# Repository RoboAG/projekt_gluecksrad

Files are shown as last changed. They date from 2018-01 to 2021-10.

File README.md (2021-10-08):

# projekt_gluecksrad
Bau eines elektrischen Glücksrades für schulische Veranstaltungen



Hier gibt es eine kleines [Demo-Video](https://www.youtube.com/watch?v=hORIZUaodIo&list=PL4P27g8g4QtTZY6d-4PRqTHP1PGKIp_SS) und eine [Bedienungsanleitung](Software/Keplertag_2021/README.md)([pdf](Anleitung/Anleitung_Bedienung.pdf)).

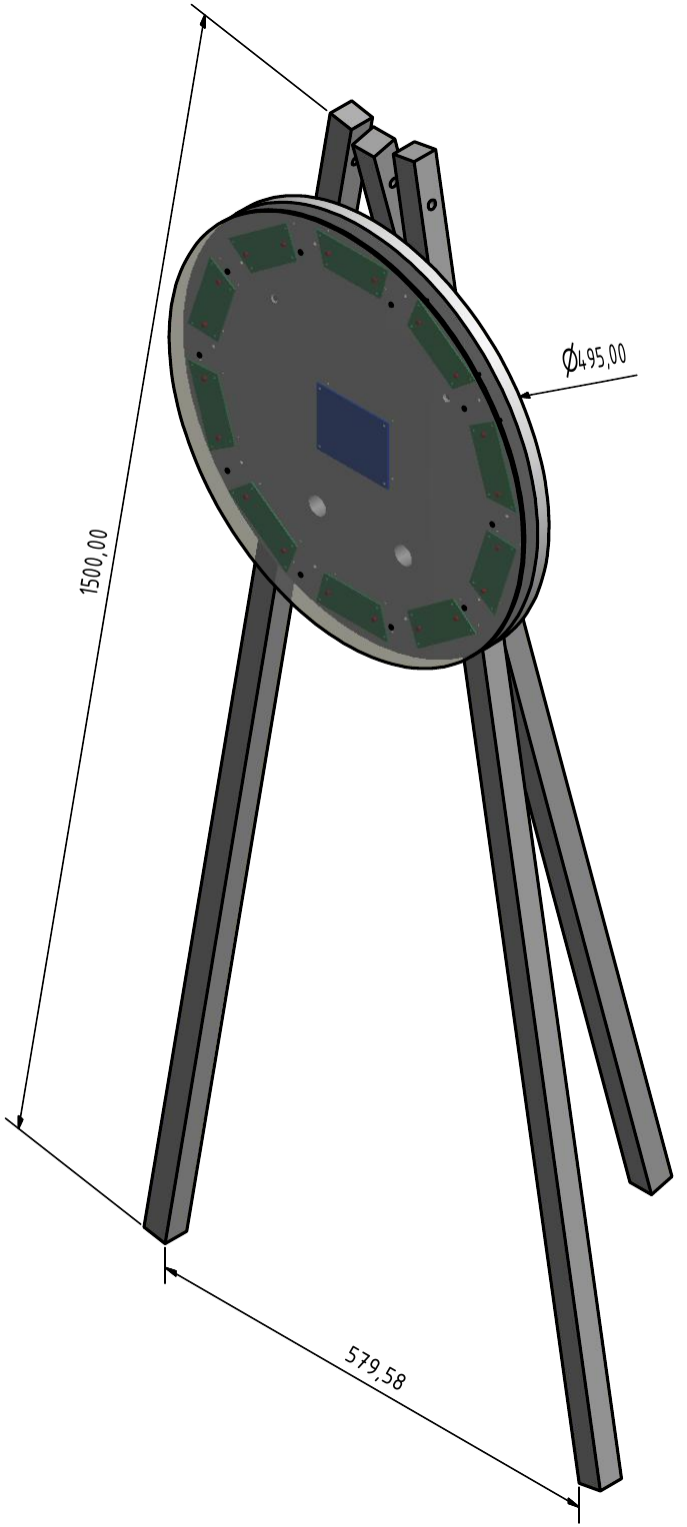
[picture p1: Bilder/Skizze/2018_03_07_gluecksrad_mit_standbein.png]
Skizze des geplanten Aufbaus


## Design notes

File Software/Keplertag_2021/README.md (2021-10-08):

# Glücksrad

## Hardware
Die gesamte Steuerung des Glücksrades erfolgt über zwei Knöpfe:

- Bumper     : extern am Glücksrad anzuschließender goldener Riesenknopf
- Mode-Button: kleiner, roter Knopf auf der Rückseite des Glücksrades

## Start
Beim Einschalten des Glücksrades wird automatisch der letzte Modus und die gespeicherte (Rest-)Preisliste geladen.
Anschließend wird der geladene Modus durch 1-sekündiges Aufleuchten aller LEDs dargestellt.

| Farbe | Modus | Folgestatus |
| ----- | --- | --- |
| grün  | Standard | Demo-Animation |
| gelb  | Countdown  | Demo- oder Preise-Leer-Animation |
| rot | Ladefehler | Demo-Animation (wechsel zu Standard) |

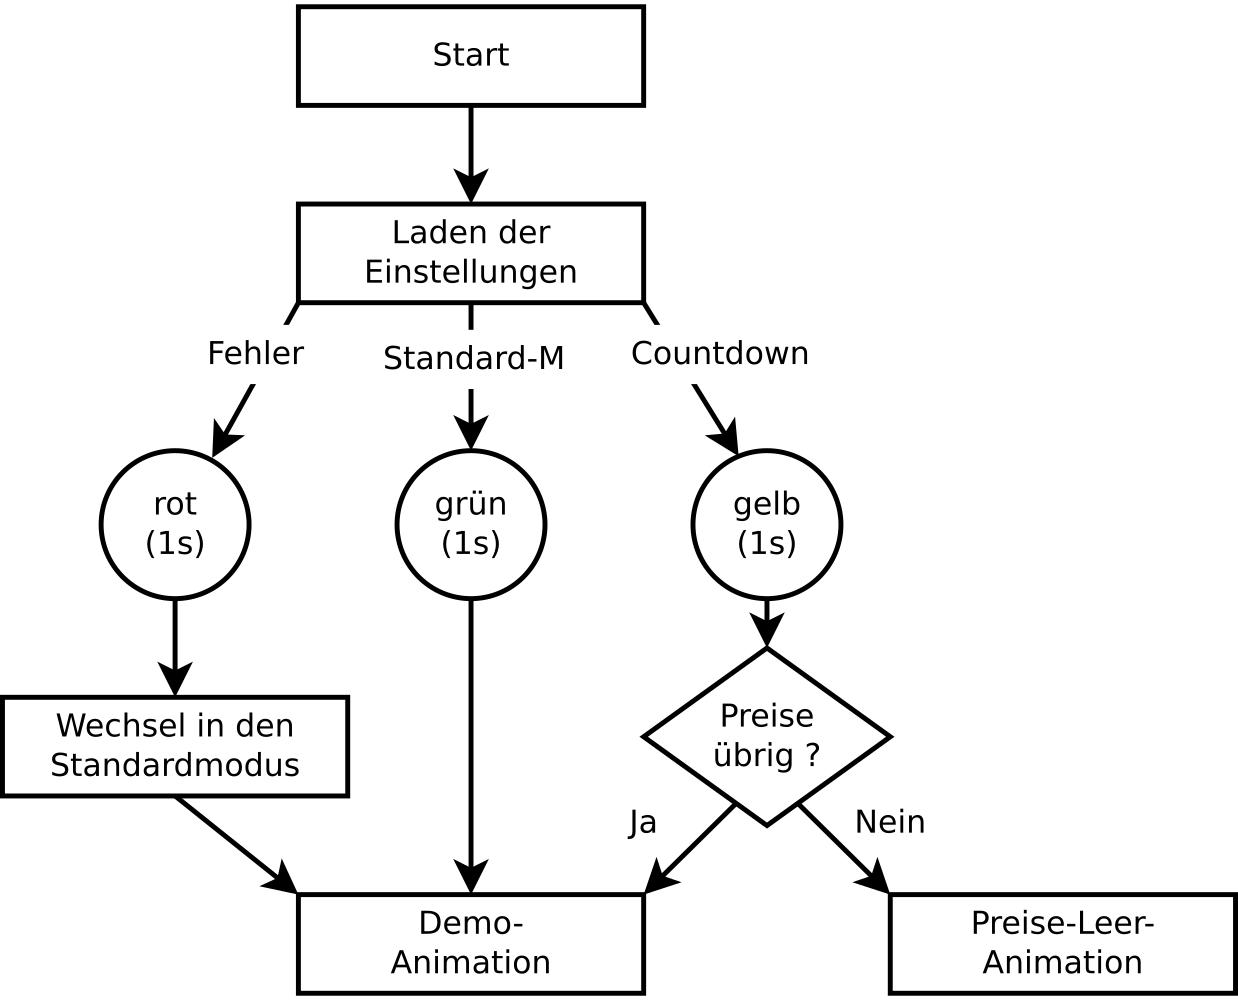
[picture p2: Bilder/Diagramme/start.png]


## Drehen & Modi
Befindet sich das Glücksrad in der Demo-Animation kann durch Drücken auf den Bumper die Drehanimation ausgelöst werden.
Sobald das Glücksrad auf einem zufälligen Feld zur Ruhe gekommen ist, startet die Preis-Animationen für die entsprechende Farbe.
Nur durch Betätigen des Mode-Button kann das Glücksrad zurück in die Demo-Animation wechseln.

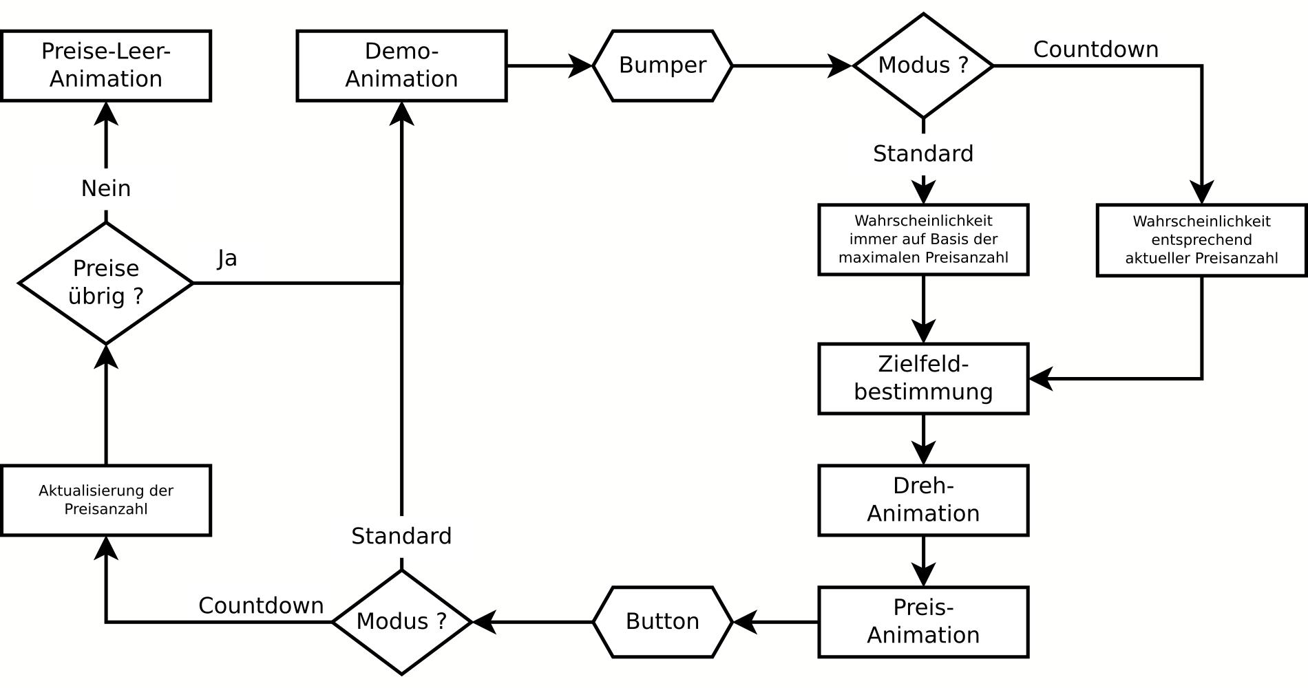
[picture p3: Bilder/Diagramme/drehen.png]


## Preise
Es gibt insgesamt fünf verschiedene Preiskategorien mit unterschiedlicher Wertigkeit.
Die Wahrscheinlichkeiten einen Preis zu erhalten ist nur abhängig von der Anzahl der hinterlegten bzw. verbleibenden Preise.

### Keplertag 2021
Beim Keplertag sind nur vier der fünf möglichen Preiskategorien belegt.

| Preis | Anzahl der LEDs | Keplertag 2021 |
| --- | --- | --- |
| rubin (rot)  |  2 von 20 (10%) | 36 |
| saphir  (blau) |  4 von 20 (20%) | 75 |
| silber  (weiß) |  7 von 20 (35%) | 750 |
| gold (gelb) |  7 von 20 (35%) | 750 |

### Frühlingsfest 2018 & 2019

| Preis | Anzahl der LEDs | Frühlingsfest 2019 | Frühlingsfest 2018 |
| --- | --- | --- | --- |
| gold (gelb) |  1 von 20 (5%)  | 9 | 5 |
| silber  (weiß) |  1 von 20 (5%)  | 11 | 15 |
| rubin (rot)  |  4 von 20 (20%) | 38 | 150 |
| smaragd (grün) |  4 von 20 (20%) | 70 | 150 |
| saphir  (blau) | 10 von 20 (50%) | 170 | 300 |

Beispielsweise war die initiale Wahrscheinlichkeit beim Frühlingsfest 2018 einen goldenen Preis zu gewinnen ca. 0.8%.

    5 / (5 + 15 + 150 + 150 + 300) ~ 0.0080645 ~ 0.8%

## Einstellungsmenü

Das Glücksrad hat ein (verstecktes) Einstellungsmenü.
Es kann nur durch 3-sekündiges Drücken des Mode-Button in der Demo- oder der Preise-Leer-Animation erreicht werden.

Der ausgewählte Menüpunkt kann durch eine kurze Betätigung des Mode-Buttons gewechselt werden:

| Menü | Bedeutung |
| ---- | --- |
| blau | Einstellungsmenü abbrechen |
| grün | Wechsel in den Standardmodus |
| gelb | Wechsel in den Countdown-Modus |
| rot  | Reset der internen Preisliste & Wechsel in den Countdown-Modus |

Durch ein 3-sekündiges Drücken des Mode-Button wird der aktuelle Menüpunkt ausgelöst.
Danach verlässt das Glücksrad das Einstellungsmenü automatisch.

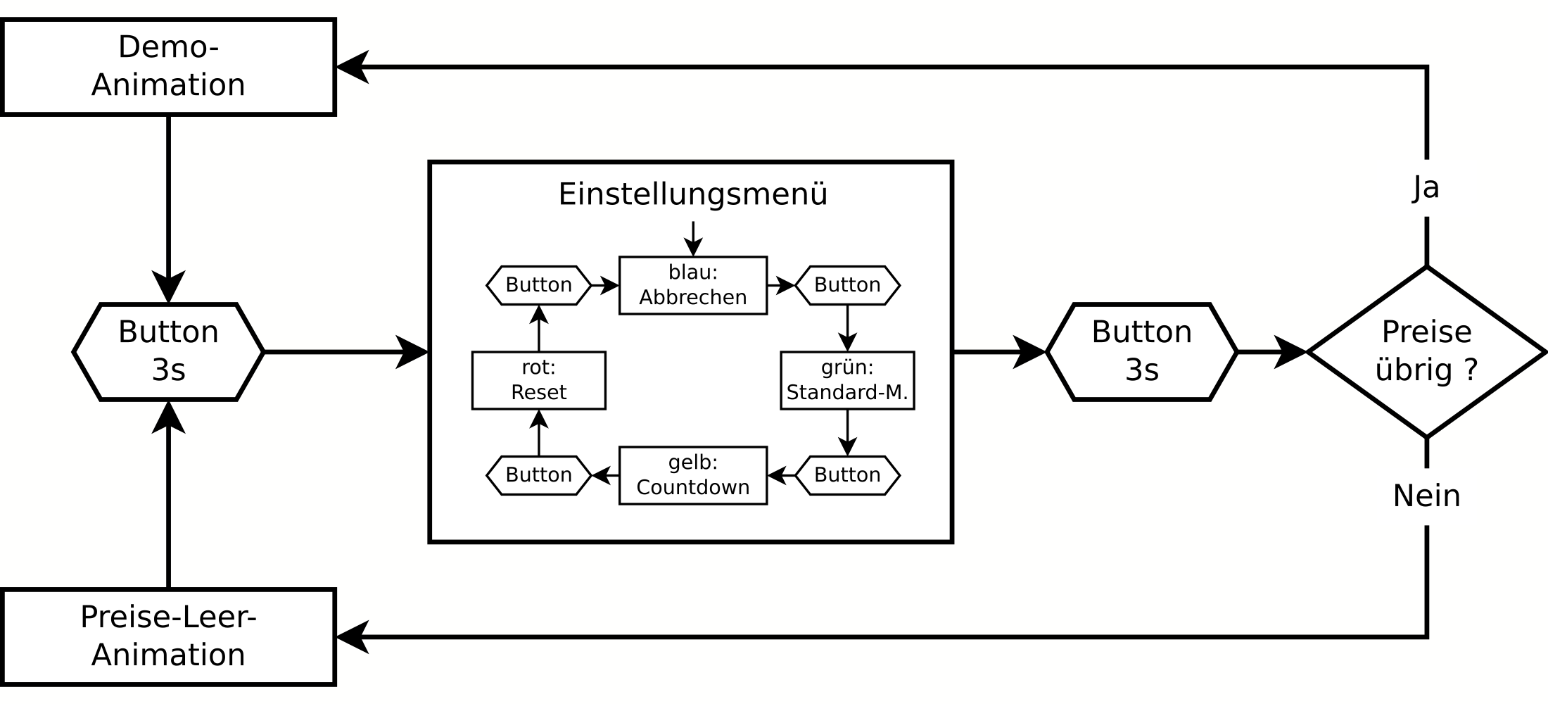
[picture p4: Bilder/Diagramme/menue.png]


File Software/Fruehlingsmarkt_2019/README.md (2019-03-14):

# Glücksrad

## Preise

- Preise
    - es gibt insgesamt 5 verschiedene Preiskategorien mit absteigender Preiswertigkeit:
        - 1: gold (gelb)
        - 2: silber (weiß)
        - 3: rubin (rot)
        - 4: smaragd (grün)
        - 5: saphir (blau)
    - die Wahrscheinlichkeiten sind im Verhältnis von verbleibender Anzahl zur übrigen Gesamtpreiszahl verteilt

## Start:

- es wird der letzte Glücksrad-Modus geladen, ggf. die gespeicherte Preisliste
- der geladene Modus wird durch 1-sekündiges Leuchten aller LEDs angezeigt:
    - grün: Standard
    - gelb: Lenz
- es startet die Demo-Animation

## Drehen:

- durch Drücken auf den Bumper im Demo-Modus wird die Dreh-Animation zu einem zufälligen Feld ausgelöst
- danach leuchten die LEDs in 3 verschiedenen Animationen (je nach Preisklasse) in der erdrehten Farbe auf
- während beider Vorgänge ist der Bumper blockiert
- durch drücken des Mode-Buttons wird die Animation beendet und der Bumper freigegeben

## Bedienung
- Buttons:
    - es gibt insgesamt zwei Buttons:
        - Bumper: extern am Glücksrad anzuschließender Riesenknopf
        - Mode:   kleiner, roter, an der Rückseite des Glücksrades befestigter Knopf

## Menü:

- durch 3-sekündiges Drücken des Mode-Buttons im Demo-Modus oder während der 'Preise-Leer' Animation wird das Menü angezeigt
- Navigiert wird mithilfe des Mode-Buttons
- Ausgewählt wird durch 3-sekündiges Drücken auf den Bumper
- zurzeit gibt es 4 Menüpunkte:
    - Blau: beendet das Menü ohne eine Aktion
    - Grün: wechselt in den Standard-Modus
    - Gelb: wechselt in den Lenz-Modus
    - Rot : resettet die Preisliste

## Modi:

- Standard
    - die Preisverteilung entspricht den Standard-Lenz-Werten und bleibt konstant
- Lenz
    - die Wahrscheinlichkeiten werden nach jedem Dreh entsprechend der Anzahl verbleibenden Preise verteilt
    - wenn alle Preise verteilt wurden (Summe der verbleibenden Preise = 0) wird dies durch eine Blink-Animation in den normalen Preisfarben kundgetan

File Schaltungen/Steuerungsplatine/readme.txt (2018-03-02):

Die Steuerungsplatine entspricht der THT-Version der Licht-Platine des RoboSAX:
    https://github.com/RoboSAX/eagle_licht

Es wird nur auf einige Bauteile bei der Bestückung verzichtet. Diese reduzierte Variante ist hier gespeichert.

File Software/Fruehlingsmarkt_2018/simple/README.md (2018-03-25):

# Glücksrad

**Allgemeines**
-------------
Allgemeine Beschreibung siehe [hier](../README.md).

**Start:**
----------
- durch gedrückt-halten des Mode-Buttons wird der Lenz-Modus geladen. Andernfalls der Standard-Modus
- der geladene Modus wird durch 1-sekündiges Leuchten aller LEDs angezeigt:
    - grün: Standard
    - gelb: Lenz
- es startet die Demo-Animation

**Resetten:**
-------------
- durch 5-sekündiges Drücken des Mode-Buttons im Demo-Modus oder bei leerer Preisliste wird diese zurückgesetzt

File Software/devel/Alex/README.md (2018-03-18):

# Glücksrad-Logik

Preisverteilung
---------------
- Kategorie 1: 300
- Kategorie 2: 150
- Kategorie 3: 150
- Kategorie 4: 15
- Kategorie 5: 5

Input-Buttons
-------------
- Button 1: 'the big Button'  - löst das Glücksrad aus
- Button 2: Freigabebutton - entsperrt Button 1
- Button 3: -

Logik
-----

**Startup:**
- Starten der Demo-Animation(en)

**Button 1:**
- Flag zur Blockierung von Button 1 setzen
- zufällige Auswahl des Zielfeldes
- ggf. neuwürfeln falls Preisklasse leer
- Dekrementieren der ausgewählten Preisklasse
- Starten der Rotationsanimation zum Zielfeldes

**Button 2:**
- entfernen der Flag zur Blockierung von Button 1

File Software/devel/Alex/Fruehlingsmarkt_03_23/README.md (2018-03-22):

Glücksrad
-----------

**Status:**

- STATE_STARTING
    - während des Startens
    - keine besondere Auswirkungen

- STATE_DEMO
    - standard Animation des Glücksrades

    - **btnBumper**:
        - startet die Drehanimation
        - state -> STATE_ROTATING
        
    - **btnMode**
        - resettet nach 5-Sekündigem gedrückt-halten die in der eeprom gespeicherten Preisanzahlen
        - während den 5 Sekunden leuchten die LEDs von grün bis hin zu rot auf
        - state -> STATE_RESET_PRICES

- STATE_ROTATING
    - Dreh-Animation
    - nach beendigung: state -> STATE_ROTATE_FINISHED
    - wenn keine Preise vorhanden: state -> STATE_PRICES_EMPTY

- STATE_ROTATE_FINISHED
    - lässt ausgewählte LED schnell blinken, bis btnMode gedrückt wird

    - **btnMode**:
        - wenn Preise vorhanden: state -> STATE_DEMO
        - sonst state -> STATE_PRICES_EMPTY

- STATE_RESET_PRICES
    - leds grün -> rot animation
    - nach 5 Sekunden:
        - resettet die Preisanzahlen in der eeprom
        - state -> STATE_PRICES_RESETTED

- STATE_PRICES_RESETTED
    - lässt alle leds für 3 Sekunden lang rot blinken

- STATE_PRICES_EMPTY
    - blinkt durchgängig in den Glücksrad-Farben

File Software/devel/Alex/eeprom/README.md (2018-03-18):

eeprom test
-----------

- get address and show it in binary code if address != 0
    - begin: white led, binary code is red

writes 16 bit data to eeprom and then reads it. Check by 16 LEDs
writing: led 1 is blue
reading: led 1 is green

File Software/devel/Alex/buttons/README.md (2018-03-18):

button test
-----------

buttons (1..3) are enabling their corresponding LEDs

info: uses LED_API_1

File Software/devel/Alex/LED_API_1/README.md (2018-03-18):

LED-APi 1
---------

uses an BGR-Byte-Array as basis
```c
{
    b1, g1, r1, 
    b2, g2, r2, 
    b3, ...
}
```

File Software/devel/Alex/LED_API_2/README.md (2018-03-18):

LED-APi 2
---------

uses an array of structs with RGB bytes as basis
```c
{ 
    { r: r1, g: g1, b: b1 }, 
    { r: r2, g: g2, b: b2 }, 
    ...
}
```

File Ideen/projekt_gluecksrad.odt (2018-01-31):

Mateial

- Grundplatte aus Holz – wird gestrichen
- Deckel aus Plexiglas

Äußeres

- Rund – ca. 50cm Durchmesser
- 24 – Led-Felder
- In der Mitte einen Buzzer
- Mit Gestell zum Hinstellen (Dreibein ?)

Elektronik

- Ein/Aus-Schalter
- externe Versorgung (Netzteil)
- evtl. auch Batterie/Akku-Betrieb ?
- einen Zentralen Controller - Atmega
- Alle Led-Platinchen sind per Bus mit MCU verbunden

Elektronischen Bauteile:

- 8-Bit Schieberegister; smd; 16 pins SMD HC 595 0,20€
- 3-Farben Led; smd LRTB G6TG 0,99€ ok
- 3-Farben Led; smd LED SMD 3528 RGB 0,68€ ok
- 2-Farben Led LED 8 RG-3 0,28€ ok
- 3-Farben Led LED RGB-5 KLAR 1,80€ ok

Projekt Glücksrad

RobotikAG des JKG 22.04.16

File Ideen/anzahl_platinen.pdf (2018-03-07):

## Glücksrad

~ Anzahl der LED-Platinen ~

Peter Weissig | Seite 1 von 1 | 07.03.2018
Anzahl | Winkel Leds | Abstand vom Mittelpunkt
Platinen | Leds | | Rand innen | Mitte | Rand außen
8 | 16 | 22,50 | 148,39 | 163,39 | 178,39
9 | 18 | 20,00 | 169,32 | 184,32 | 199,32
10 | 20 | 18,00 | 190,20 | 205,20 | 220,20
11 | 22 | 16,36 | 211,04 | 226,04 | 241,04
12 | 24 | 15,00 | 231,86 | 246,86 | 261,86
13 | 26 | 13,85 | 252,66 | 267,66 | 282,66
14 | 28 | 12,86 | 273,45 | 288,45 | 303,45
15 | 30 | 12,00 | 294,22 | 309,22 | 324,22

Der Durchmesser des Glücksrads ist 495mm.
Also sollten die Platinenaußenlöcher bei <250mm liegen.

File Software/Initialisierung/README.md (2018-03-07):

Die Initialisierung entspricht der der THT-Version der Licht-Platine des RoboSAX:
    https://github.com/RoboSAX/eagle_licht

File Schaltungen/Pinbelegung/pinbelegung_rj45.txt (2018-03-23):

Pinbelegung des RJ45-Anschlusses
================================

Pin      Taster   Programmer  Platine
(RJ45)   (RJ11)   (AVR ISP)
1                 1           MISO
2                 3           SCK
3        1                    BTN-Mode
4        2                    BTN-Mode
5        3        6           Masse
6        4        6           Masse
7                 4           MOSI
8                 5           RESET
Schirm            2           Vcc

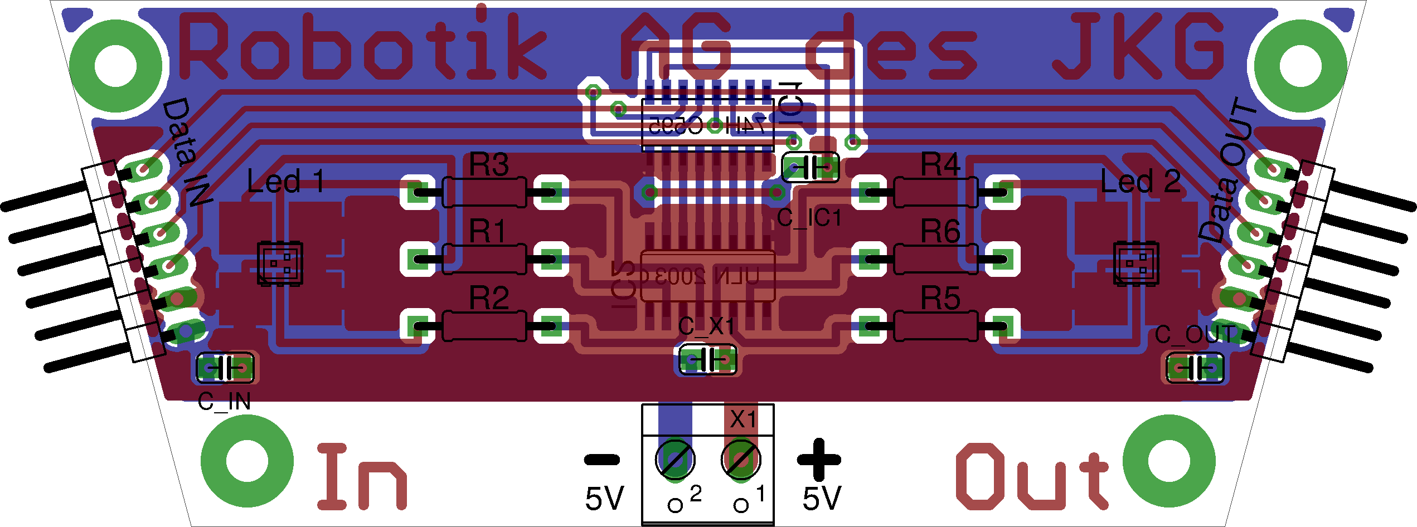
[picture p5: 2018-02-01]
Schaltungen/LED-Platine/2018_01_31_neu/export/images/all.png

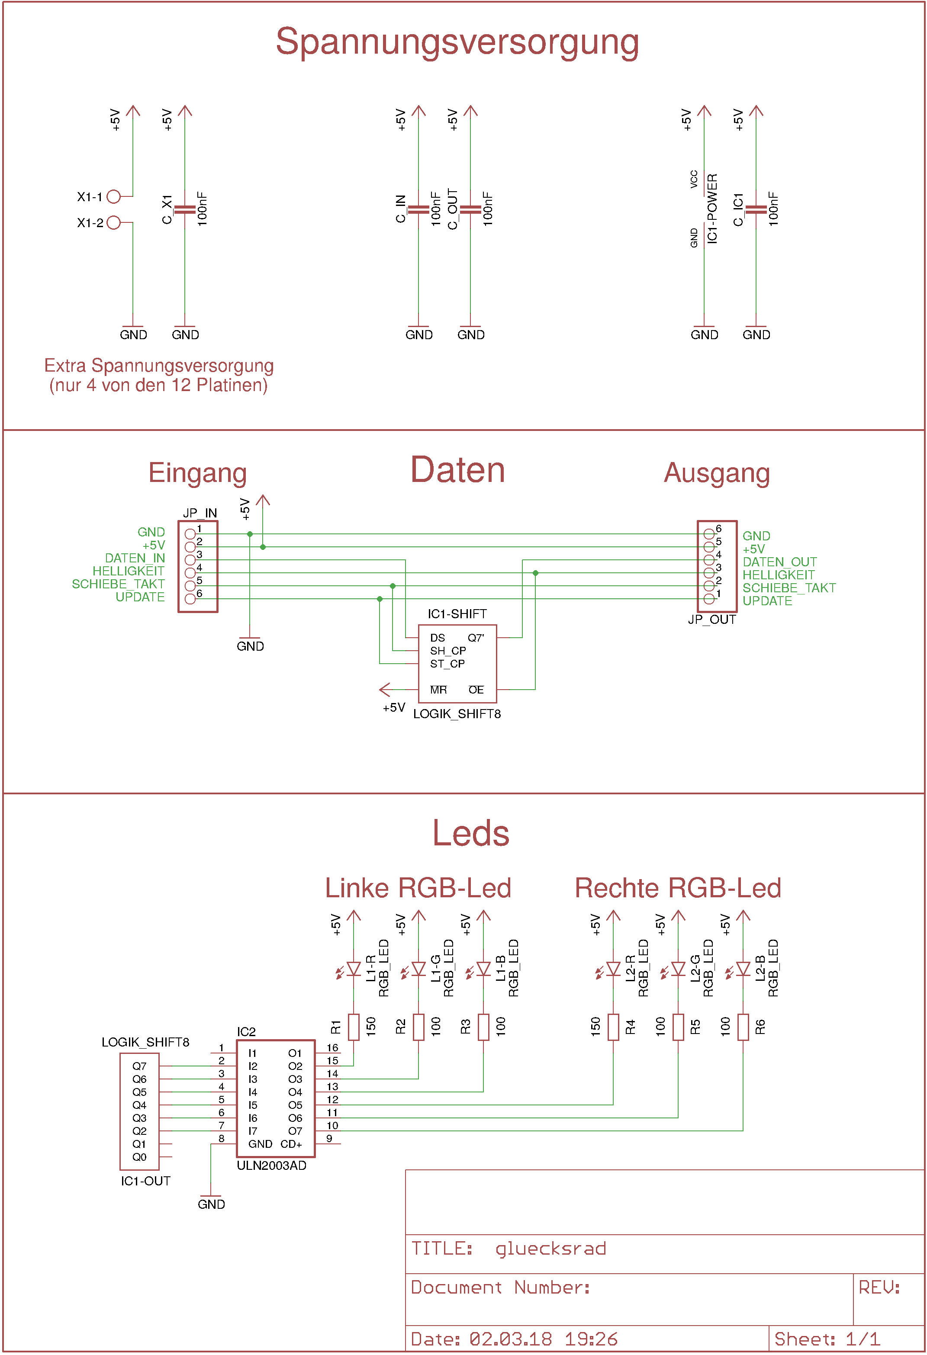
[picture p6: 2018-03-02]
Schaltungen/LED-Platine/2018_01_31_neu/export/images/circuit.png

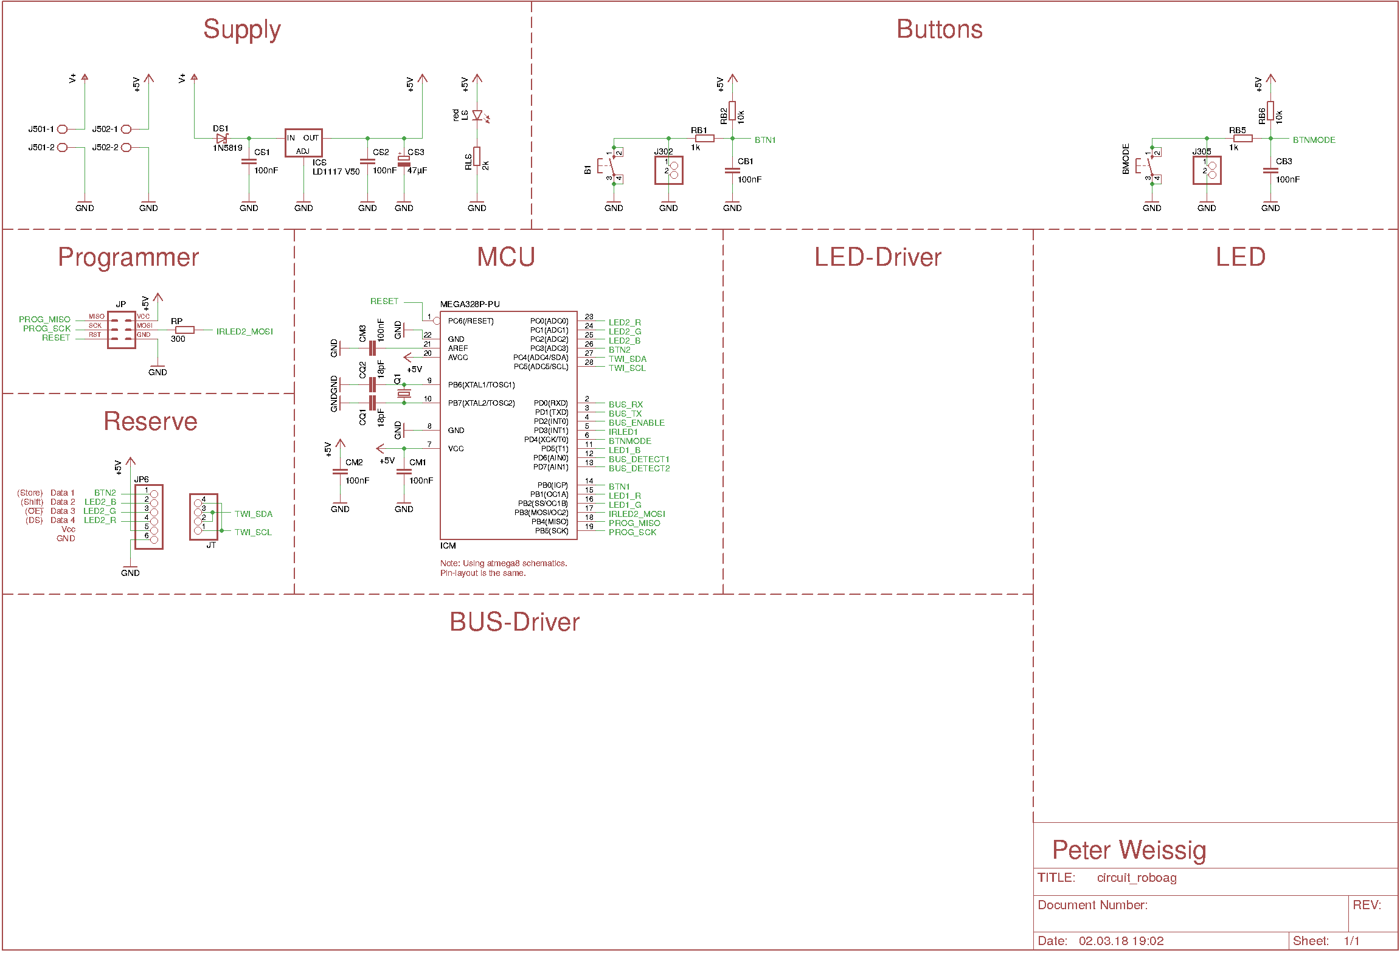
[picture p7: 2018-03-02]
Schaltungen/Steuerungsplatine/export/images/circuit_roboag.png

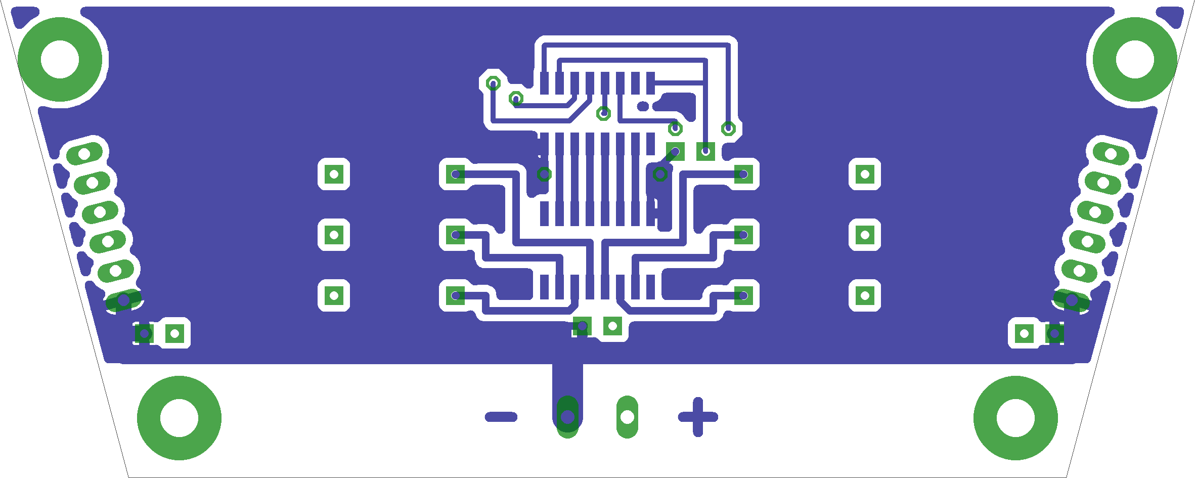
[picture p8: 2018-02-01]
Schaltungen/LED-Platine/2018_01_31_neu/export/images/layout_bottom.png

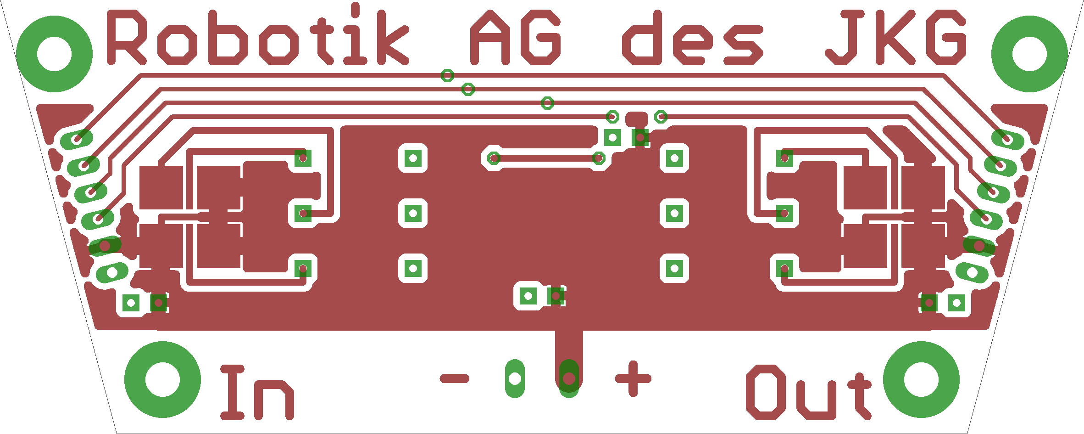
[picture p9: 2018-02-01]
Schaltungen/LED-Platine/2018_01_31_neu/export/images/layout_top.png

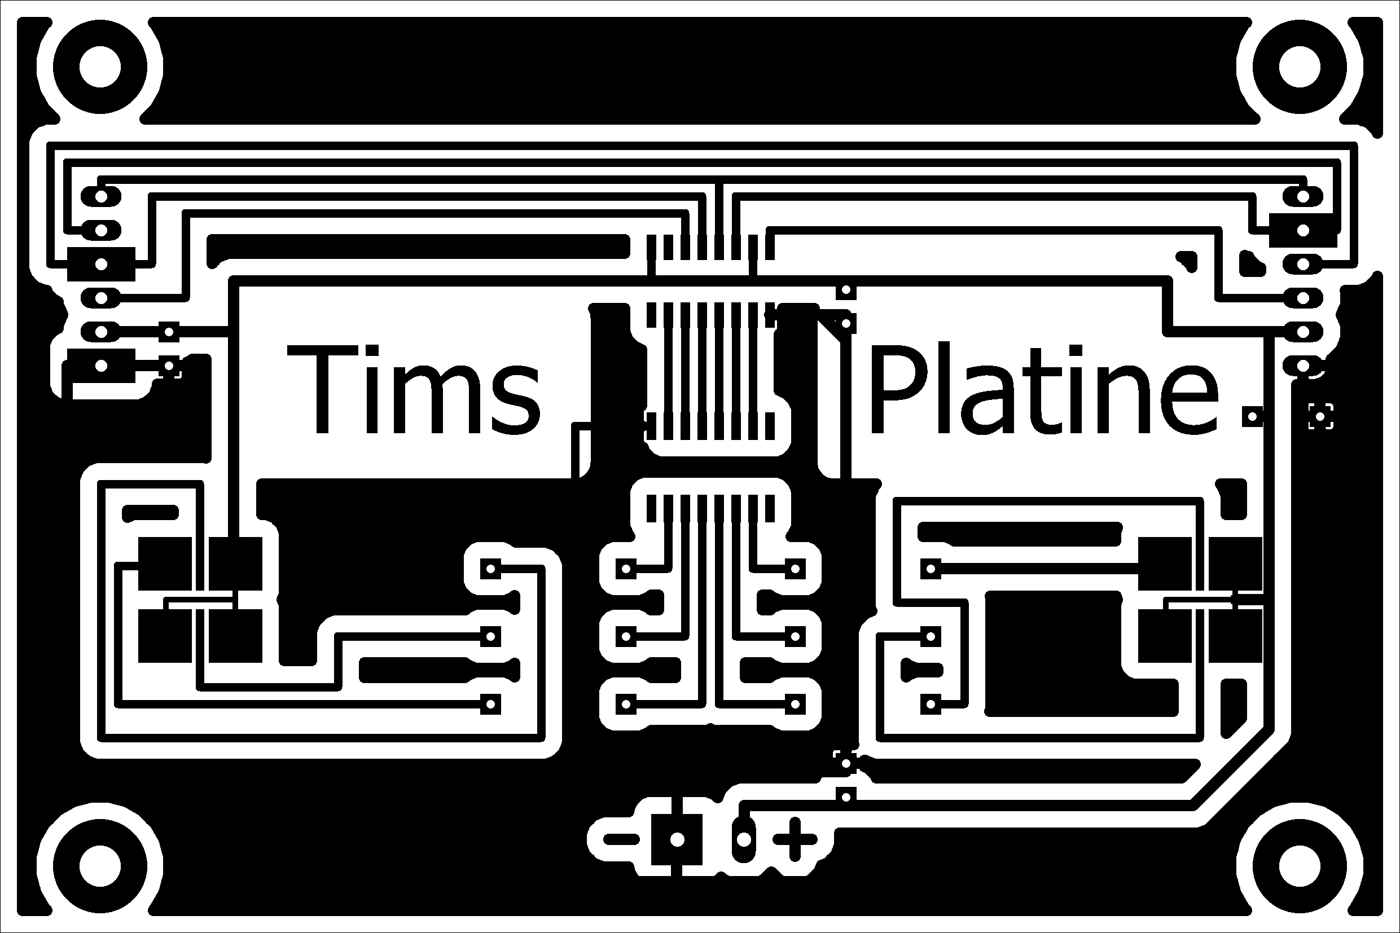
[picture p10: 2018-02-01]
Schaltungen/LED-Platine/2017_06_25_tim/layout_bw.png

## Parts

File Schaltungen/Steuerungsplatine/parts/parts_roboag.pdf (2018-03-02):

## RoboSAX light tht

Peter Weissig | Seite 1 von 2 | 02.03.2018
Name | Value / Description | Order code | # | Prize | Sum
button; 6x6mm; h=5mm | 2 | 0,13 € | 0,26 €
CQ1, CQ2 | 18pF; 2,5mm | 2 | 0,06 € | 0,12 €
100nF; 2,5mm | 7 | 0,05 € | 0,35 €
CS3 | 47µF; 2mm; d=5mm | 1 | 0,03 € | 0,03 €
DS | low drop | 1 | 0,06 € | 0,06 €
ICM | atmega 328P | 1 | 2,50 € | 2,50 €
ICS | low-drop; 5V; 1A | 1 | 0,51 € | 0,51 €
JP6 | special pin head; 90°; 1x6 | 1 | 0,14 € | 0,14 €
JT | female header; 1x4 pins | 1 | 0,16 € | 0,16 €
| | 0,25 | 0,27 € | -
JP | box header; 2x3 pins | 1 | 0,16 € | 0,16 €
J501, J502 | connecting teminal; 2x | 2 | 0,31 € | 0,62 €
| 3mm; 2mA, red | 1 | 0,09 € | 0,09 €
Q1 | crystal; 16 MHz | 1 | 0,22 € | 0,22 €
RP | 300 | 1 | 0,05 € | 0,05 €
| 1k | 2 | 0,05 € | 0,10 €
| 2k | 1 | 0,05 € | 0,05 €
| 10k | 2 | 0,05 € | 0,10 €

5,52 €

B1, B2, BMODE | TASTER 9302 (https://www.reichelt.de/Kurzhubtaster/TASTER-9302/3/index.html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) KERKO 18P (https://www.reichelt.de/Kurzhubtaster/TASTER-9302/3/index.html?ACTION=3;ARTICLE=9274)
CB1, CB2, CB3 CM1, CM2, CM3, CD3, CS1, CS2 | X7R-2,5 100N (https://www.reichelt.de/Kurzhubtaster/TASTER-9302/3/index.html?ACTION=3;ARTICLE=22853)
| RAD 105 47/35 (https://www.reichelt.de/Kurzhubtaster/TASTER-9302/3/index.html?ACTION=3;ARTICLE=42399)
| 1N 5819 (https://www.reichelt.de/1N-UF-AA-Dioden/1N-4151-DIO/3/index.html?ACTION=3;ARTICLE=41850)

ATMEGA 328P-PU (https://www.reichelt.de/1N-UF-AA-Dioden/1N-4151-DIO/3/index.html?ACTION=3;ARTICLE=119685)
LD1117 V50 (https://www.reichelt.de/1N-UF-AA-Dioden/1N-4151-DIO/3/index.html?ACTION=3;ARTICLE=200893)

PSS 254/6W (https://www.reichelt.de/Platinen-Steckverbinder/PSS-254-2G/3/index.html?ACTION=3;ARTICLE=217631)
MPE 094-1-004 (https://www.reichelt.de/Buchsenleisten/MPE-094-1-004/3/index.html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)
BL 1X20G8 2,54 (https://www.reichelt.de/Buchsenleisten/MPE-094-1-004/3/index.html?ACTION=3;ARTICLE=51827)
WSL 6G (https://www.reichelt.de/Stiftleisten/RND-205-00623/3/index.html?ACTION=3;ARTICLE=85732)

AKL 101-02 (https://www.reichelt.de/Buchsenleisten/MPE-094-1-005/3/index.html?ACTION=3;ARTICLE=36605)

LD1, LS | LED 3MM 2MA RT (https://www.reichelt.de/Platinen-Steckverbinder/PSK-254-2W/3/index.html?ACTION=3;ARTICLE=21626)
| 16,0000-HC49U-S (https://www.reichelt.de/Platinen-Steckverbinder/PSK-254-2W/3/index.html?ACTION=3;ARTICLE=32852)

METALL 300 (https://www.reichelt.de/Platinen-Steckverbinder/PSK-254-2W/3/index.html?ACTION=3;ARTICLE=11715)
RB1, RB3, RB5,
RD5, RD7

METALL 1,00K (https://www.reichelt.de/Platinen-Steckverbinder/PSK-254-2W/3/index.html?ACTION=3;ARTICLE=11403)

RLD1, RLD2, RLS | METALL 2,00K (https://www.reichelt.de/Platinen-Steckverbinder/PSK-254-2W/3/index.html?ACTION=3;ARTICLE=11578)
RB2, RB4, RB6, RD8, RD9 | METALL 10,0K (https://www.reichelt.de/Platinen-Steckverbinder/PSK-254-2W/3/index.html?ACTION=3;ARTICLE=11449)

## Additionals

Peter Weissig | Seite 2 von 2 | 02.03.2018
Related Part | Value / Description | Order code | # | Prize | Sum
ICM | ic socket; 2x14 | 1 | 0,10 € | 0,10 €
JP6 | special socket; 1x6 pins | 1 | 0,07 € | 0,07 €
pins for special connector | 0,29 € | 0,29 €
J501 | wire; 2x0,75mm²; power | 10,30 € | 0,21 €
JP6 | wire; 10x0,1mm²; data | 8,60 € | 0,57 €
JP6 | shrink tubing; d=1,6mm; b (https://www.reichelt.de/Schrumpfschlauch-Abschnitte/SDH-1-6-SW/3/index.html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) | 0,25 € | 0,03 €
JP6 | shrink tubing; d=1,6mm; r | 0,32 € | 0,03 €
JP6 | shrink tubing; d=1,6mm; b (https://www.reichelt.de/Schrumpfschlauch-Abschnitte/SDH-1-6-SW/3/index.html?ACTION=3;ARTICLE=17392) | 0,32 € | 0,03 €
button; signal | 2 | 0,47 € | 0,94 €
ICS | screw; m3; 8mm | 1,99 € | 0,01 €
ICS | nut; m3 | 2,50 € | 0,03 €
| washer; m3 | 1,85 € | 0,11 €
| screw; 2,9mm | 1,75 € | 0,11 €

2,52 €

GS 28-S (https://www.reichelt.de/?ACTION=3;ARTICLE=86281)

PSK 254/6W (https://www.reichelt.de/Platinen-Steckverbinder/PSK-KONTAKTE/3/index.html?ACTION=3;ARTICLE=147625)
J301, J302, J303, J304,
J305, JP6
PSK-KONTAKTE (https://www.reichelt.de/Platinen-Steckverbinder/PSK-KONTAKTE/3/index.html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) | 6 (20)
LA 275-50 (https://www.reichelt.de/Pfosten-Wannenstecker/2/index.html?ACTION=3;ARTICLE=36246) | 3 (50)
AWG 28-10G 30M (https://www.reichelt.de/Flachbandkabel/AWG-28-10G-30M/3/index.html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) | 2 (30)
SDH 1,6 SW (https://www.reichelt.de/Schrumpfschlauch-Abschnitte/SDH-1-6-SW/3/index.html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) | 1 (10)
SDH 1,6 RT (https://www.reichelt.de/Schrumpfschlauch-Abschnitte/SDH-1-6-SW/3/index.html?ACTION=3;ARTICLE=17393) | 1 (10)
SDH 1,6 BL (https://www.reichelt.de/Schrumpfschlauch-Abschnitte/SDH-1-6-SW/3/index.html?ACTION=3;ARTICLE=17392) | 1 (10)
B1, B2, BMODE | T 113A RT (https://www.reichelt.de/Drucktaster-Druckschalter/T-113A-RT/3/index.html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)
SZK M3X8-200 (https://www.reichelt.de/Flachbandkabel/AWG-28-10G-30M/3/index.html?ACTION=3;ARTICLE=65693) | 1 (200)
SK-E M3-100 (https://www.reichelt.de/Flachbandkabel/AWG-28-10G-30M/3/index.html?ACTION=3;ARTICLE=72592) | 1 (100)

ICS,
corners of circuit board
SKU-E 3,2-100 (https://www.reichelt.de/Flachbandkabel/AWG-28-10G-30M/3/index.html?ACTION=3;ARTICLE=72588) | 6 (100)

corners of circuit board,
battery clip
SBL 2916-100 (https://www.reichelt.de/Blechschrauben/SBL-2913-100/3/index.html?ACTION=3;ARTICLE=130327) | 6 (100)

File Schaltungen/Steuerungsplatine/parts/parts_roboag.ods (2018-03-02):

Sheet: RoboSAX light tht
Name | Value / Description | Order code | # | Prize | Sum
B1, B2, BMODE | button; 6x6mm; h=5mm | TASTER 9302 (https://www.reichelt.de/Kurzhubtaster/TASTER-9302/3/index.html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) | 2 | 0,13 € | 0,26 €
CQ1, CQ2 | 18pF; 2,5mm | KERKO 18P (https://www.reichelt.de/Kurzhubtaster/TASTER-9302/3/index.html?ACTION=3;ARTICLE=9274) | 2 | 0,06 € | 0,12 €
CB1, CB2, CB3 CM1, CM2, CM3, CD3, CS1, CS2 | 100nF; 2,5mm | X7R-2,5 100N (https://www.reichelt.de/Kurzhubtaster/TASTER-9302/3/index.html?ACTION=3;ARTICLE=22853) | 7 | 0,05 € | 0,35 €
CS3 | 47µF; 2mm; d=5mm | RAD 105 47/35 (https://www.reichelt.de/Kurzhubtaster/TASTER-9302/3/index.html?ACTION=3;ARTICLE=42399) | 1 | 0,03 € | 0,03 €
DS | low drop | 1N 5819 (https://www.reichelt.de/1N-UF-AA-Dioden/1N-4151-DIO/3/index.html?ACTION=3;ARTICLE=41850) | 1 | 0,06 € | 0,06 €
ICM | atmega 328P | ATMEGA 328P-PU (https://www.reichelt.de/1N-UF-AA-Dioden/1N-4151-DIO/3/index.html?ACTION=3;ARTICLE=119685) | 1 | 2,50 € | 2,50 €
ICS | low-drop; 5V; 1A | LD1117 V50 (https://www.reichelt.de/1N-UF-AA-Dioden/1N-4151-DIO/3/index.html?ACTION=3;ARTICLE=200893) | 1 | 0,51 € | 0,51 €
JP6 | special pin head; 90°; 1x6 pins | PSS 254/6W (https://www.reichelt.de/Platinen-Steckverbinder/PSS-254-2G/3/index.html?ACTION=3;ARTICLE=217631) | 1 | 0,14 € | 0,14 €
JT | female header; 1x4 pins | MPE 094-1-004 (https://www.reichelt.de/Buchsenleisten/MPE-094-1-004/3/index.html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) | 1 | 0,16 € | 0,16 €
 |  | BL 1X20G8 2,54 (https://www.reichelt.de/Buchsenleisten/MPE-094-1-004/3/index.html?ACTION=3;ARTICLE=51827) | 0,25 | 0,27 € | -
JP | box header; 2x3 pins | WSL 6G (https://www.reichelt.de/Stiftleisten/RND-205-00623/3/index.html?ACTION=3;ARTICLE=85732) | 1 | 0,16 € | 0,16 €
J501, J502 | connecting teminal; 2x | AKL 101-02 (https://www.reichelt.de/Buchsenleisten/MPE-094-1-005/3/index.html?ACTION=3;ARTICLE=36605) | 2 | 0,31 € | 0,62 €
LD1, LS | 3mm; 2mA, red | LED 3MM 2MA RT (https://www.reichelt.de/Platinen-Steckverbinder/PSK-254-2W/3/index.html?ACTION=3;ARTICLE=21626) | 1 | 0,09 € | 0,09 €
Q1 | crystal; 16 MHz | 16,0000-HC49U-S (https://www.reichelt.de/Platinen-Steckverbinder/PSK-254-2W/3/index.html?ACTION=3;ARTICLE=32852) | 1 | 0,22 € | 0,22 €
RP | 300 | METALL 300 (https://www.reichelt.de/Platinen-Steckverbinder/PSK-254-2W/3/index.html?ACTION=3;ARTICLE=11715) | 1 | 0,05 € | 0,05 €
RB1, RB3, RB5, RD5, RD7 | 1k | METALL 1,00K (https://www.reichelt.de/Platinen-Steckverbinder/PSK-254-2W/3/index.html?ACTION=3;ARTICLE=11403) | 2 | 0,05 € | 0,10 €
RLD1, RLD2, RLS | 2k | METALL 2,00K (https://www.reichelt.de/Platinen-Steckverbinder/PSK-254-2W/3/index.html?ACTION=3;ARTICLE=11578) | 1 | 0,05 € | 0,05 €
RB2, RB4, RB6, RD8, RD9 | 10k | METALL 10,0K (https://www.reichelt.de/Platinen-Steckverbinder/PSK-254-2W/3/index.html?ACTION=3;ARTICLE=11449) | 2 | 0,05 € | 0,10 €
 |  |  | 5,52 €

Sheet: Additionals
Related Part | Value / Description | Order code | # | Prize | Sum
ICM | ic socket; 2x14 | GS 28-S (https://www.reichelt.de/?ACTION=3;ARTICLE=86281) | 1 | 0,10 € | 0,10 €
JP6 | special socket; 1x6 pins | PSK 254/6W (https://www.reichelt.de/Platinen-Steckverbinder/PSK-KONTAKTE/3/index.html?ACTION=3;ARTICLE=147625) | 1 | 0,07 € | 0,07 €
J301, J302, J303, J304, J305, JP6 | pins for special connector | PSK-KONTAKTE (https://www.reichelt.de/Platinen-Steckverbinder/PSK-KONTAKTE/3/index.html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) | 6 (20) | 0,29 € | 0,29 €
J501 | wire; 2x0,75mm²; power | LA 275-50 (https://www.reichelt.de/Pfosten-Wannenstecker/2/index.html?ACTION=3;ARTICLE=36246) | 3 (50) | 10,30 € | 0,21 €
JP6 | wire; 10x0,1mm²; data | AWG 28-10G 30M (https://www.reichelt.de/Flachbandkabel/AWG-28-10G-30M/3/index.html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) | 2 (30) | 8,60 € | 0,57 €
JP6 | shrink tubing; d=1,6mm; black | SDH 1,6 SW (https://www.reichelt.de/Schrumpfschlauch-Abschnitte/SDH-1-6-SW/3/index.html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) | 1 (10) | 0,25 € | 0,03 €
JP6 | shrink tubing; d=1,6mm; red | SDH 1,6 RT (https://www.reichelt.de/Schrumpfschlauch-Abschnitte/SDH-1-6-SW/3/index.html?ACTION=3;ARTICLE=17393) | 1 (10) | 0,32 € | 0,03 €
JP6 | shrink tubing; d=1,6mm; blue | SDH 1,6 BL (https://www.reichelt.de/Schrumpfschlauch-Abschnitte/SDH-1-6-SW/3/index.html?ACTION=3;ARTICLE=17392) | 1 (10) | 0,32 € | 0,03 €
B1, B2, BMODE | button; signal | T 113A RT (https://www.reichelt.de/Drucktaster-Druckschalter/T-113A-RT/3/index.html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) | 2 | 0,47 € | 0,94 €
ICS | screw; m3; 8mm | SZK M3X8-200 (https://www.reichelt.de/Flachbandkabel/AWG-28-10G-30M/3/index.html?ACTION=3;ARTICLE=65693) | 1 (200) | 1,99 € | 0,01 €
ICS | nut; m3 | SK-E M3-100 (https://www.reichelt.de/Flachbandkabel/AWG-28-10G-30M/3/index.html?ACTION=3;ARTICLE=72592) | 1 (100) | 2,50 € | 0,03 €
ICS, corners of circuit board | washer; m3 | SKU-E 3,2-100 (https://www.reichelt.de/Flachbandkabel/AWG-28-10G-30M/3/index.html?ACTION=3;ARTICLE=72588) | 6 (100) | 1,85 € | 0,11 €
corners of circuit board, battery clip | screw; 2,9mm | SBL 2916-100 (https://www.reichelt.de/Blechschrauben/SBL-2913-100/3/index.html?ACTION=3;ARTICLE=130327) | 6 (100) | 1,75 € | 0,11 €
 |  |  | 2,52 €

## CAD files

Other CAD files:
Zeichnungen/Details/Gluecksrad.dwg
Zeichnungen/Details/Gluecksrad_gesamt.iam
Zeichnungen/Details/Grundplatte.ipt
Zeichnungen/Details/Platine_MCU.ipt
Zeichnungen/Details/Platine_led.ipt
Zeichnungen/Details/Plexiglas.ipt
Zeichnungen/Details/Standbein_aussen.ipt
Zeichnungen/Details/Standbein_mitte.ipt
Zeichnungen/Details/Zusatzelemente/licht_taster.ipt

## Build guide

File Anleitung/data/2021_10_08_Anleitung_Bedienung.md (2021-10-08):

% Glücksrad
% RoboAG des JKG (PW)
% 08.10.2021

---
toc: true
---

## Hardware
Die gesamte Steuerung des Glücksrades erfolgt über zwei Knöpfe:

- Bumper     : extern am Glücksrad anzuschließender goldener Riesenknopf
- Mode-Button: kleiner, roter Knopf auf der Rückseite des Glücksrades

## Start
Beim Einschalten des Glücksrades wird automatisch der letzte Modus und die gespeicherte (Rest-)Preisliste geladen.
Anschließend wird der geladene Modus durch 1-sekündiges Aufleuchten aller LEDs dargestellt.

 \hspace{3cm} 

## Drehen & Modi
Befindet sich das Glücksrad in der Demo-Animation kann durch Drücken auf den Bumper die Drehanimation ausgelöst werden.
Sobald das Glücksrad auf einem zufälligen Feld zur Ruhe gekommen ist, startet die Preis-Animationen für die entsprechende Farbe.
Nur durch Betätigen des Mode-Button kann das Glücksrad zurück in die Demo-Animation wechseln.

 

## Preise
Es gibt insgesamt fünf verschiedene Preiskategorien mit unterschiedlicher Wertigkeit.
Die Wahrscheinlichkeiten einen Preis zu erhalten ist nur abhängig von der Anzahl der hinterlegten bzw. verbleibenden Preise.

Beim Keplertag 2021 sind nur vier der fünf möglichen Preiskategorien belegt.

| Preis | Anzahl der LEDs | Keplertag 2021 |
| --- | --- | --- |
| rubin (rot)  |  2 von 20 (10%) | 36 |
| saphir  (blau) |  4 von 20 (20%) | 75 |
| silber  (weiß) |  7 von 20 (35%) | 750 |
| gold (gelb) |  7 von 20 (35%) | 750 |

\newpage

## Einstellungsmenü

Das Glücksrad hat ein (verstecktes) Einstellungsmenü.
Es kann nur durch 3-sekündiges Drücken des Mode-Button in der Demo- oder der Preise-Leer-Animation erreicht werden.

Der ausgewählte Menüpunkt kann durch eine kurze Betätigung des Mode-Buttons gewechselt werden:

| Menü | Bedeutung |
| ---- | --- |
| blau | Einstellungsmenü abbrechen |
| grün | Wechsel in den Standardmodus |
| gelb | Wechsel in den Countdown-Modus |
| rot  | Reset der internen Preisliste & Wechsel in den Countdown-Modus |

Durch ein 3-sekündiges Drücken des Mode-Button wird der aktuelle Menüpunkt ausgelöst.
Danach verlässt das Glücksrad das Einstellungsmenü automatisch.



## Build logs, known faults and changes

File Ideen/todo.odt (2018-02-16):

Wer ? Wann erledigt ?

Programmierung

Ansteuerung allgemein

evtl. Soft-PWM für verschiedene Farben

Animationsfunktion

Zufallsgenerator

Modusauswahl

evtl. Modusprogrammierung

Hardware

Platinen löten

Platinen verbinden

Alles festschrauben

Buzzer einbauen

Deckplatte zurechtsägen/einbauen

Standfuß bauen

Stromversorgung machen

Allgemein

Testen

Demo und Absprache Förderverein

Projekt Glücksrad

RobotikAG des JKG 16.02.18

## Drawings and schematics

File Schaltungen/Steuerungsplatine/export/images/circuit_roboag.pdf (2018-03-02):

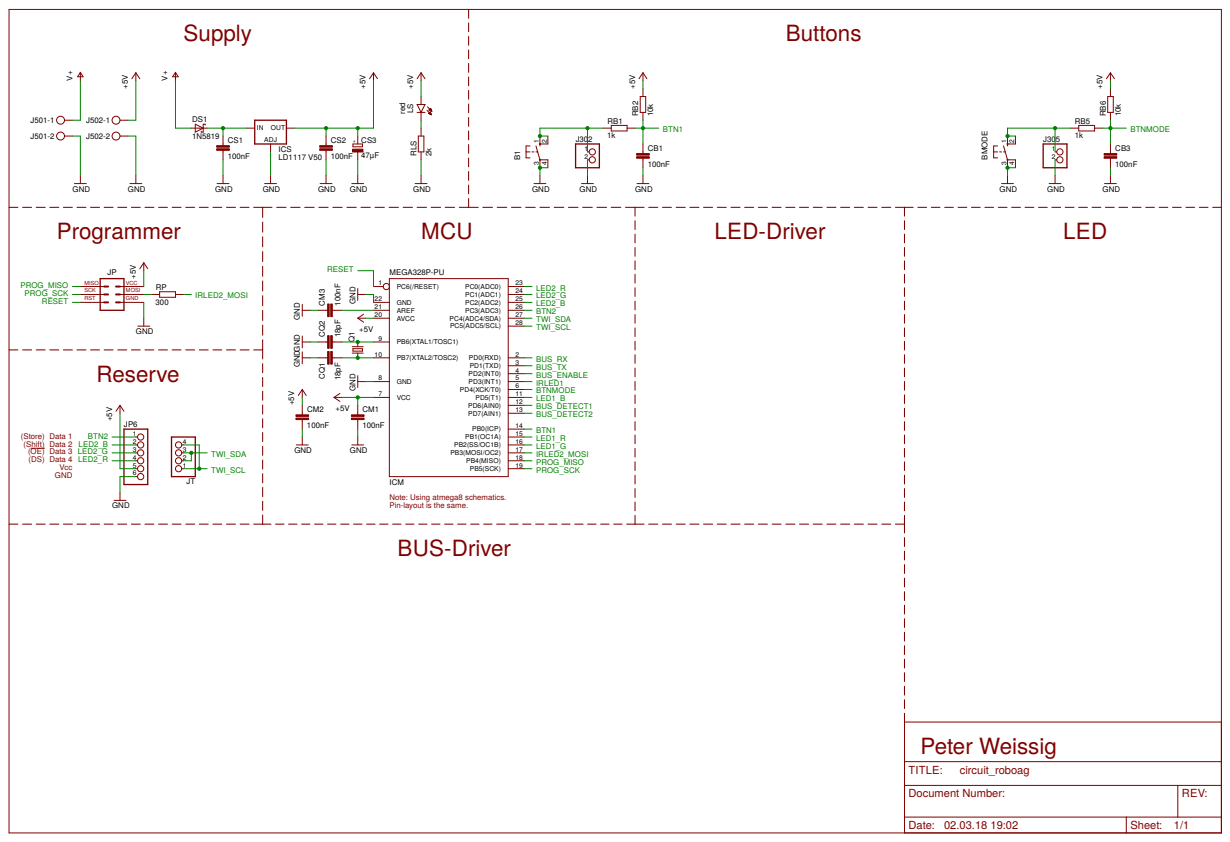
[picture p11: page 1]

ICM
Note: Using atmega8 schematics. Pin-layout is the same.
BUS-Driver

REV: TITLE: Document Number: circuit_roboag

Date: 02.03.18 19:02 | Sheet: 1/1

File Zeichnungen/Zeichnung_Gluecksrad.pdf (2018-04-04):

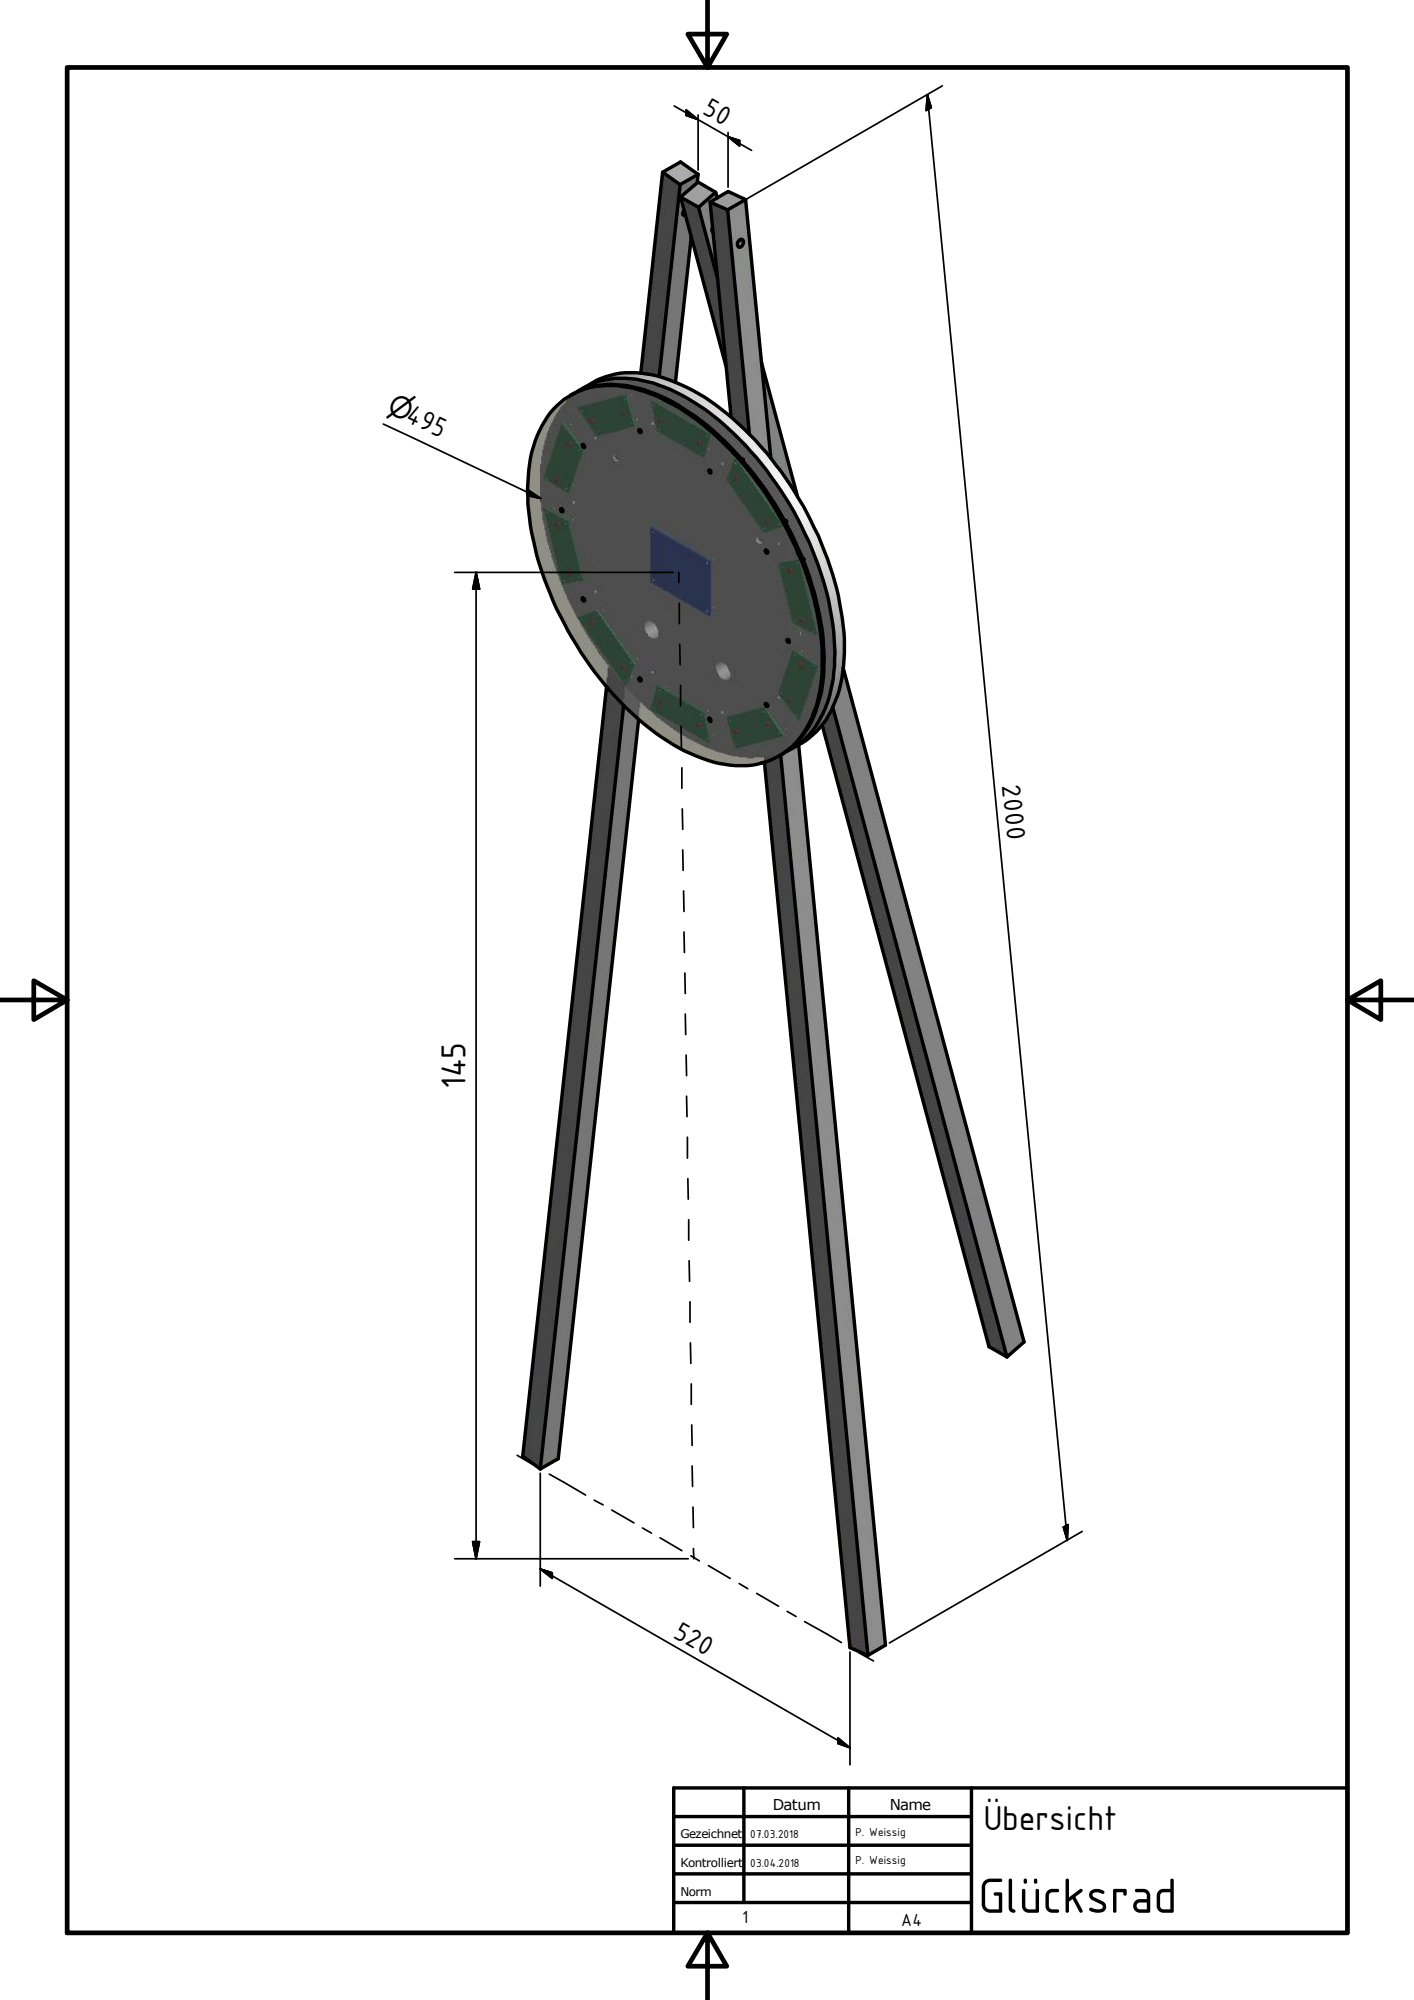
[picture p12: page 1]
Gl¯cksrad

Datum | Name | bersicht

Gezeichnet | 07.03.2018 | P. Weissig

Kontrolliert | 03.04.2018 | P. Weissig

Norm

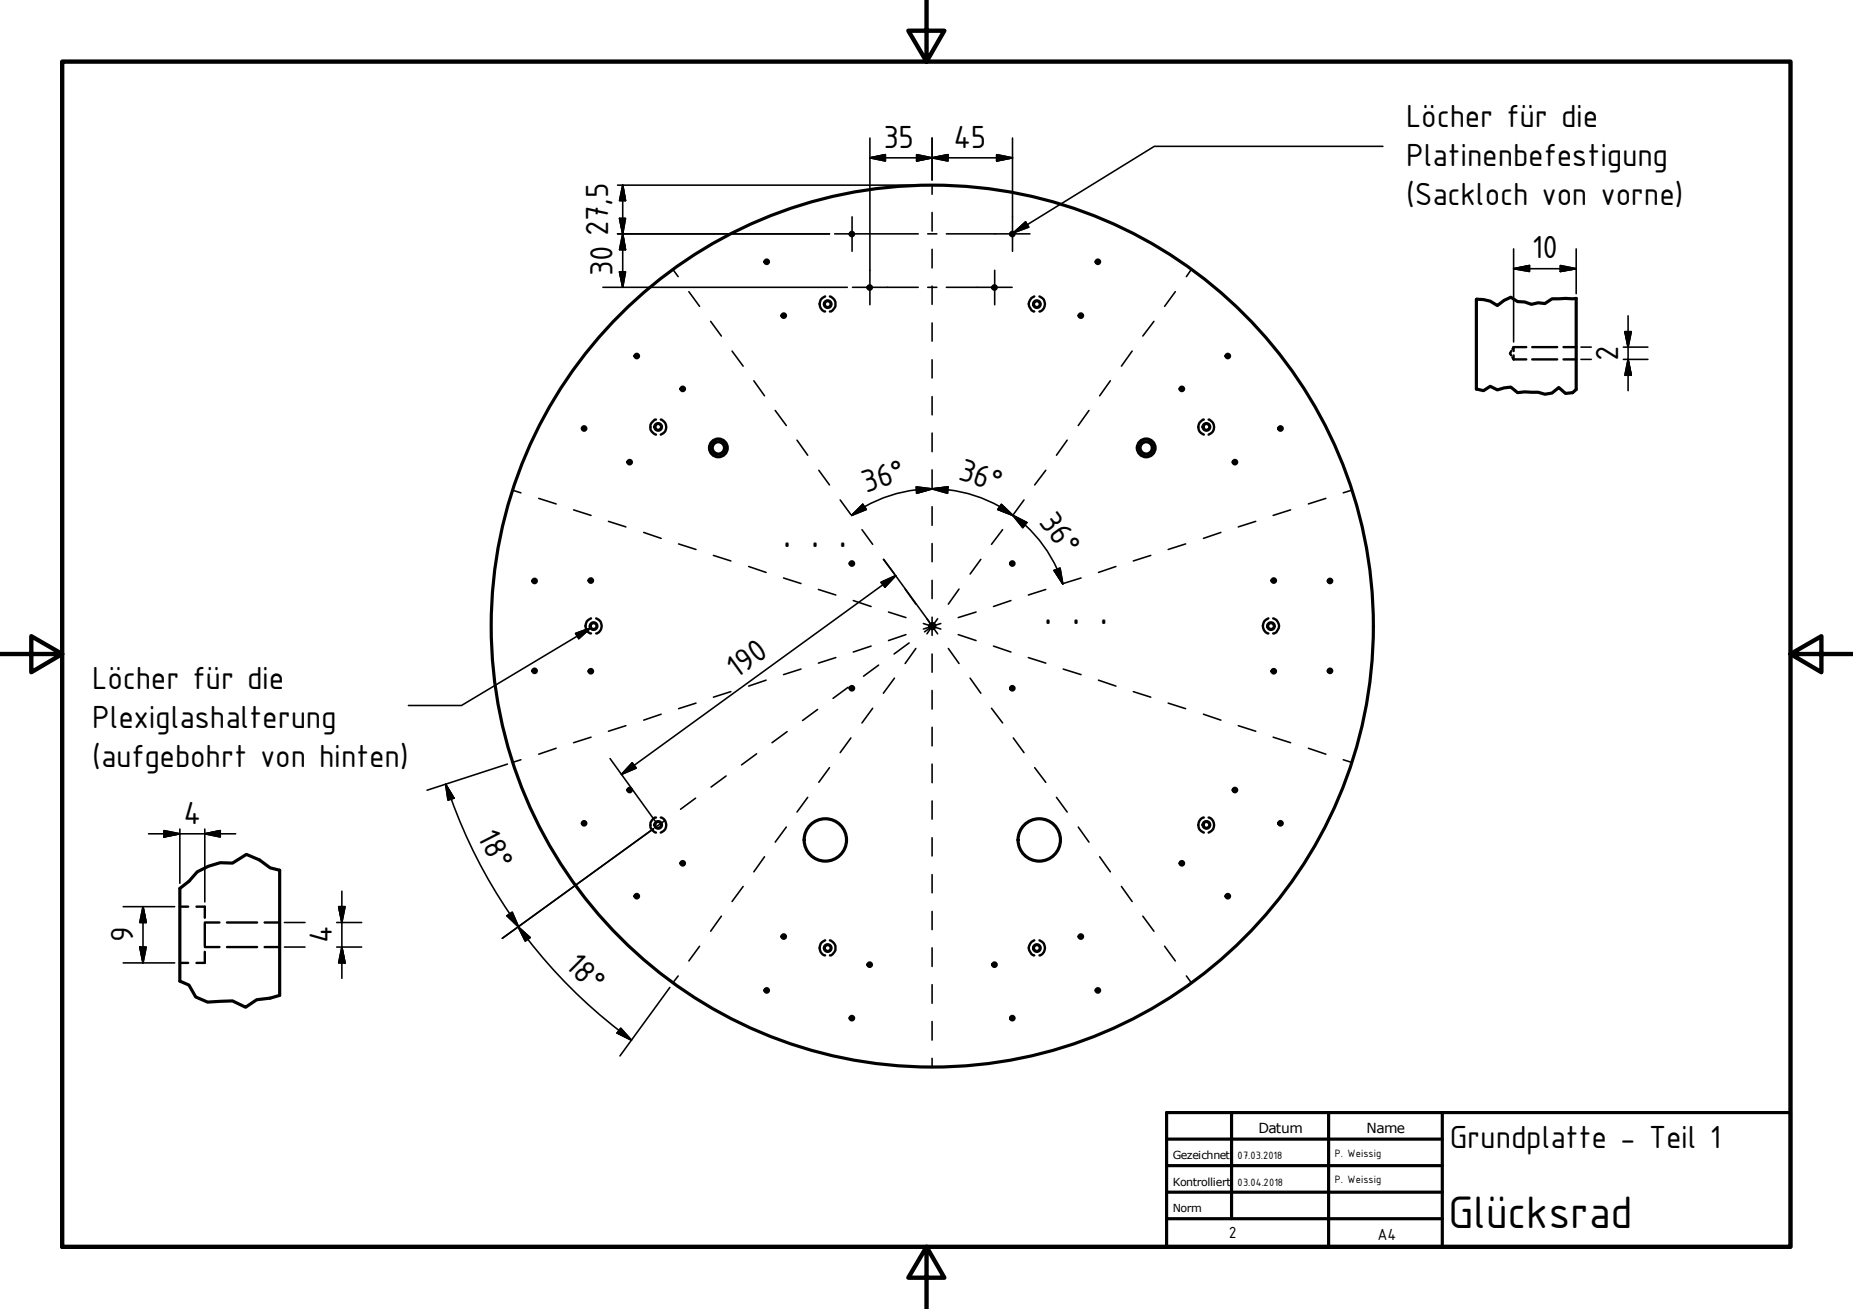
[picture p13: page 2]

L©cher f¯r die
Platinenbefestigung
(Sackloch von vorne)

Plexiglashalterung
(aufgebohrt von hinten)

Datum | Name | Grundplatte - Teil 1

Gezeichnet | 07.03.2018 | P. Weissig

Kontrolliert | 03.04.2018 | P. Weissig

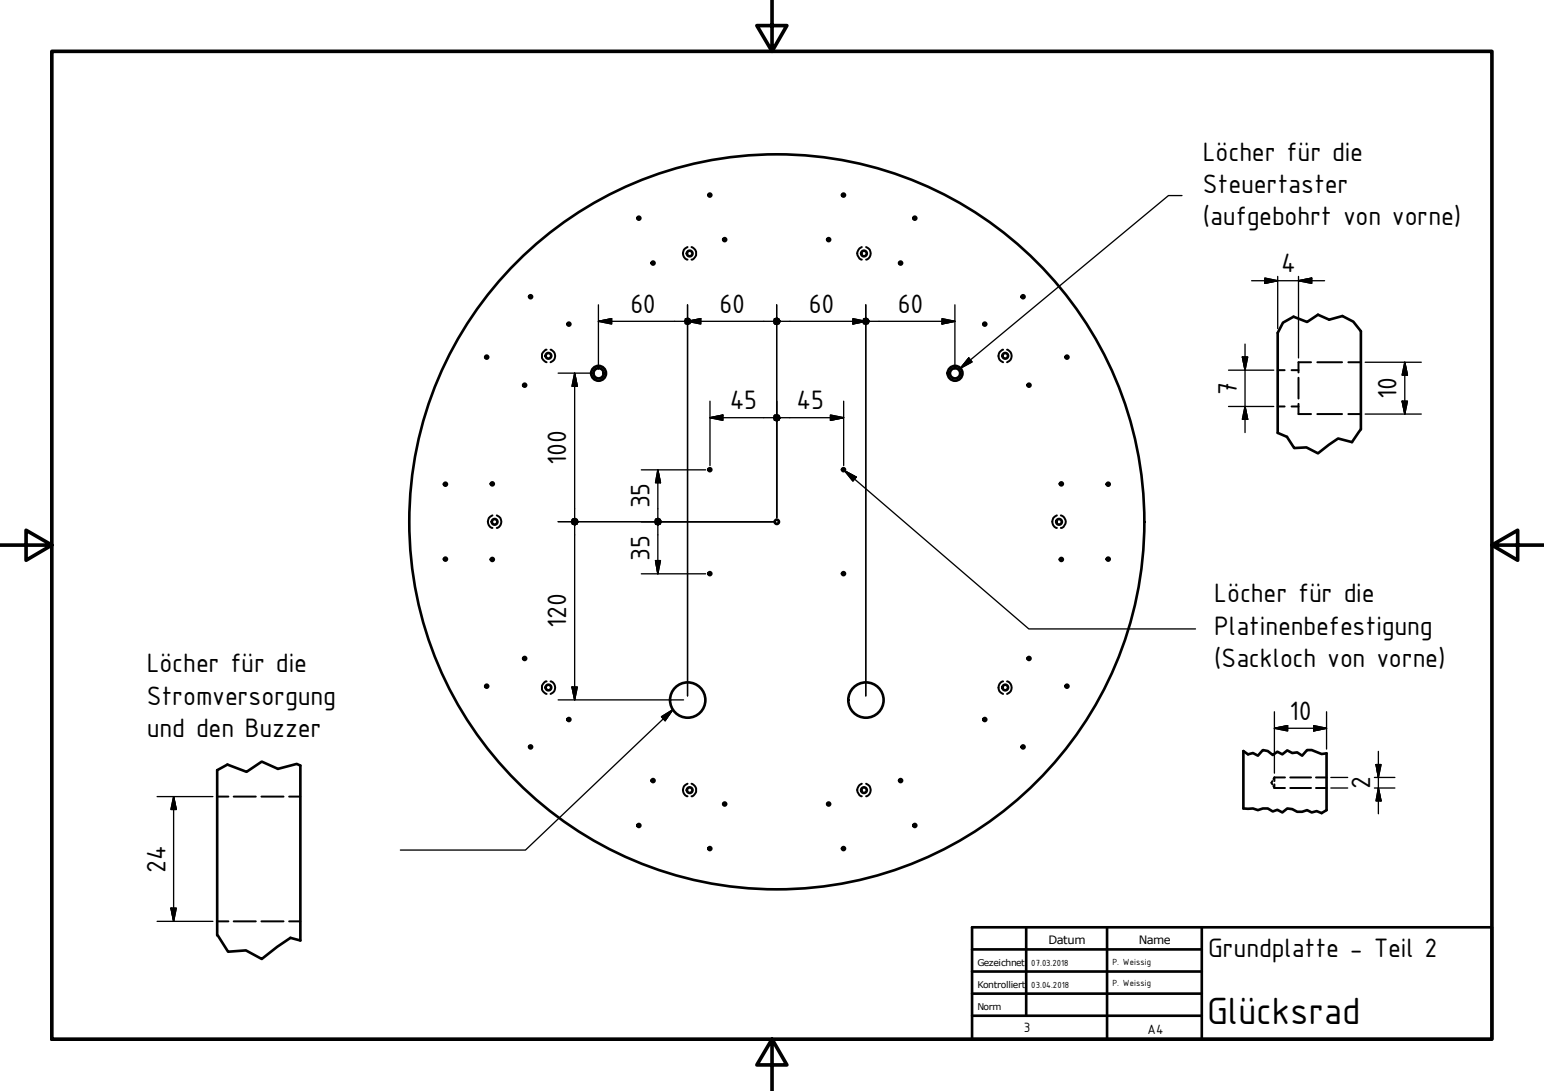
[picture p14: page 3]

L©cher f¯r die
Steuertaster
(aufgebohrt von vorne)

Platinenbefestigung
(Sackloch von vorne)

Stromversorgung
und den Buzzer

Datum | Name | Grundplatte - Teil 2

Gezeichnet | 07.03.2018 | P. Weissig

Kontrolliert | 03.04.2018 | P. Weissig

## Plexiglasplatte h=3mm

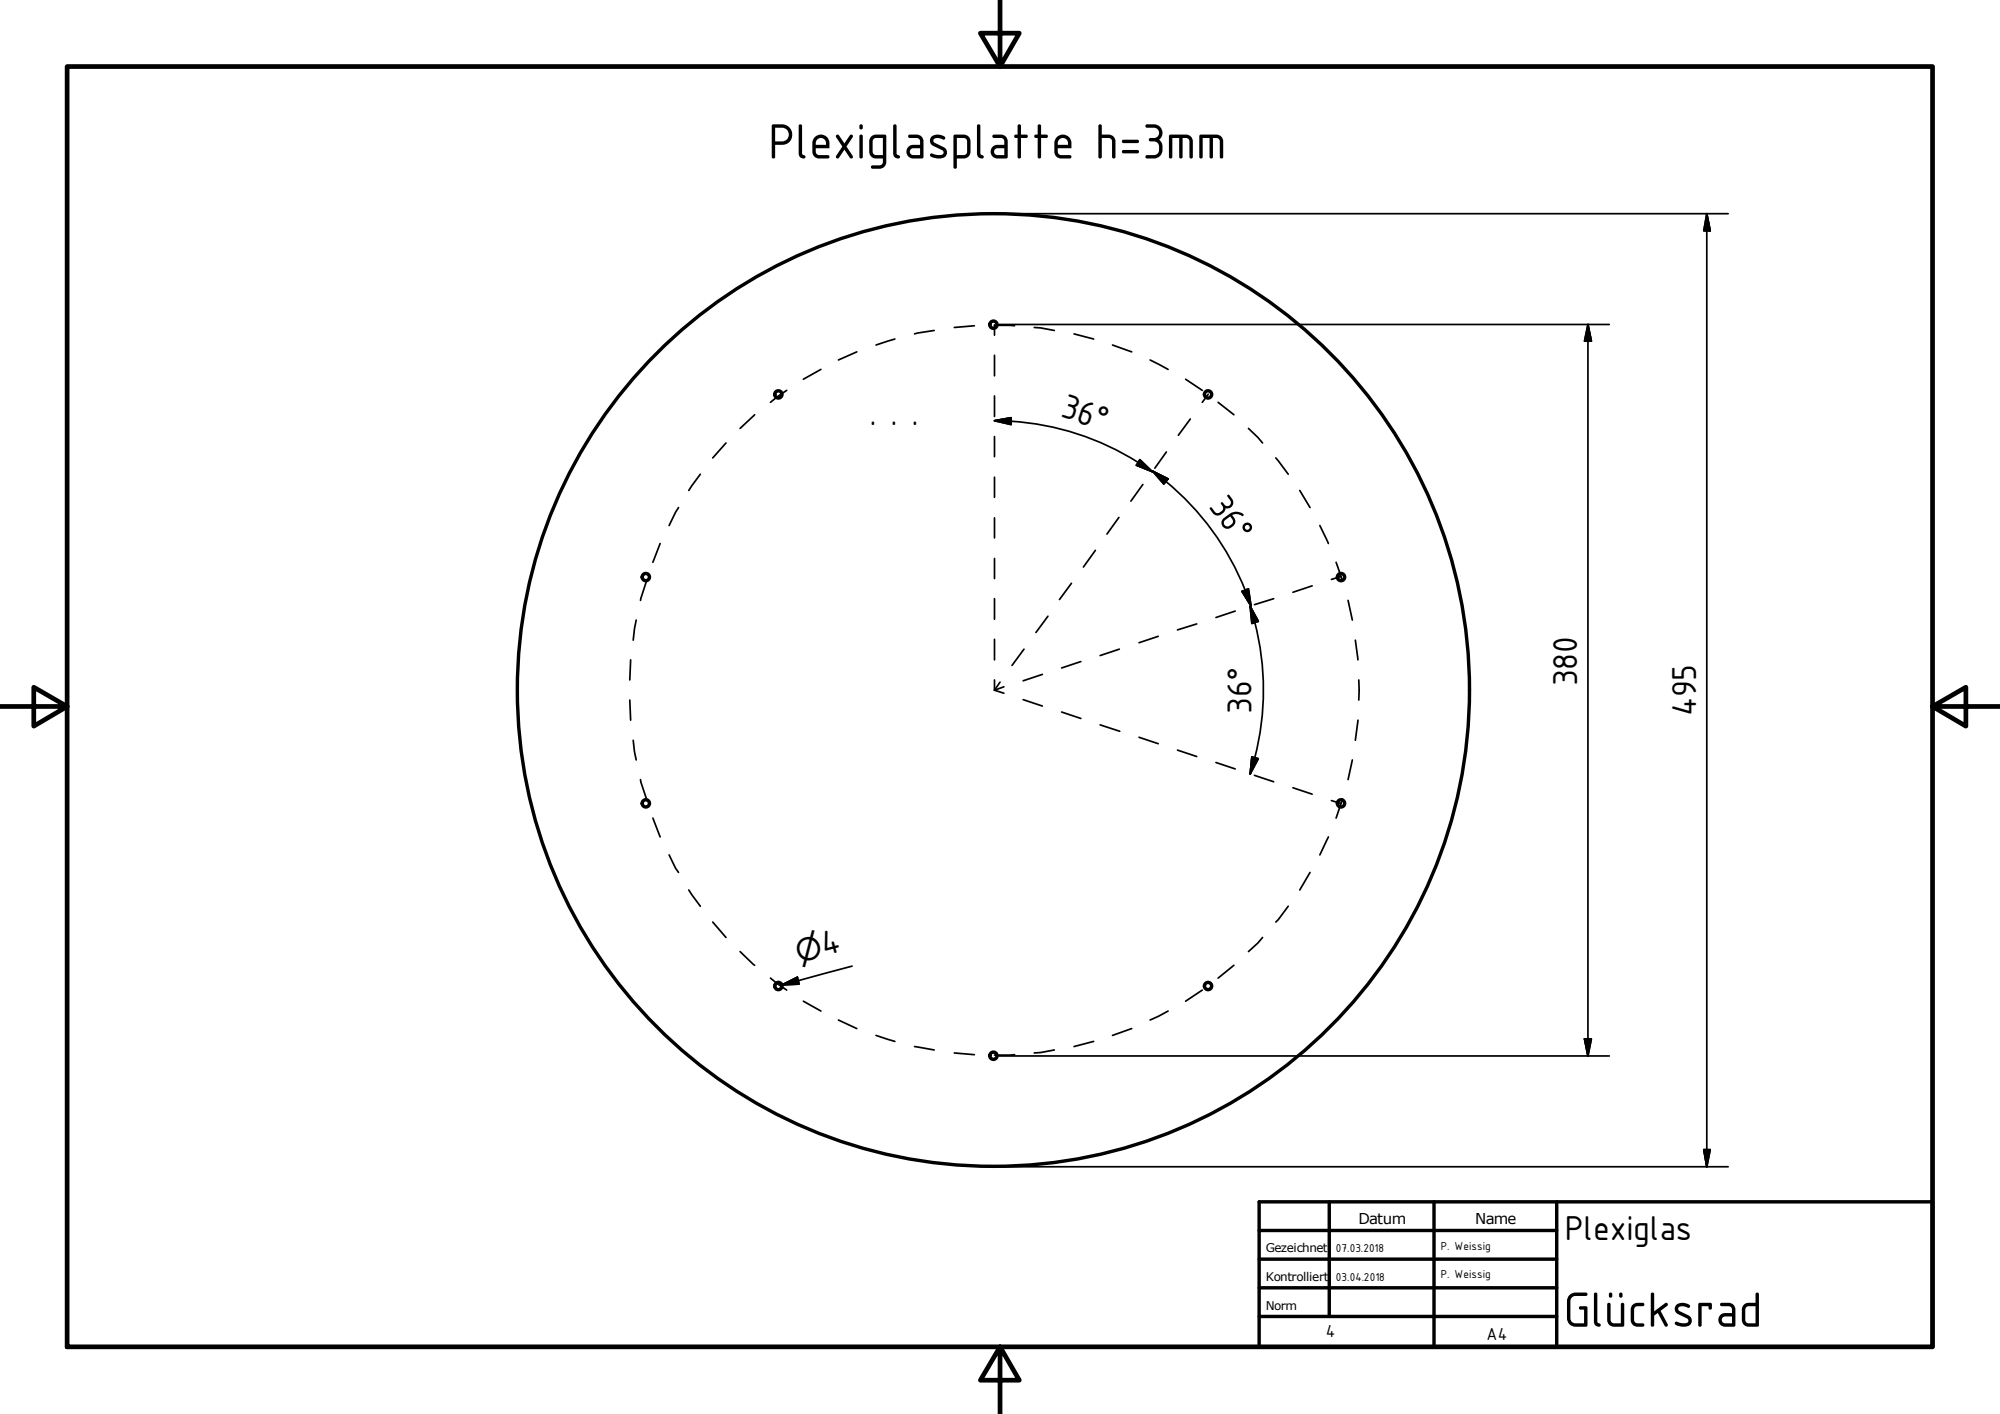
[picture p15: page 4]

Datum | Name | Plexiglas

Gezeichnet | 07.03.2018 | P. Weissig

Kontrolliert | 03.04.2018 | P. Weissig

B

C

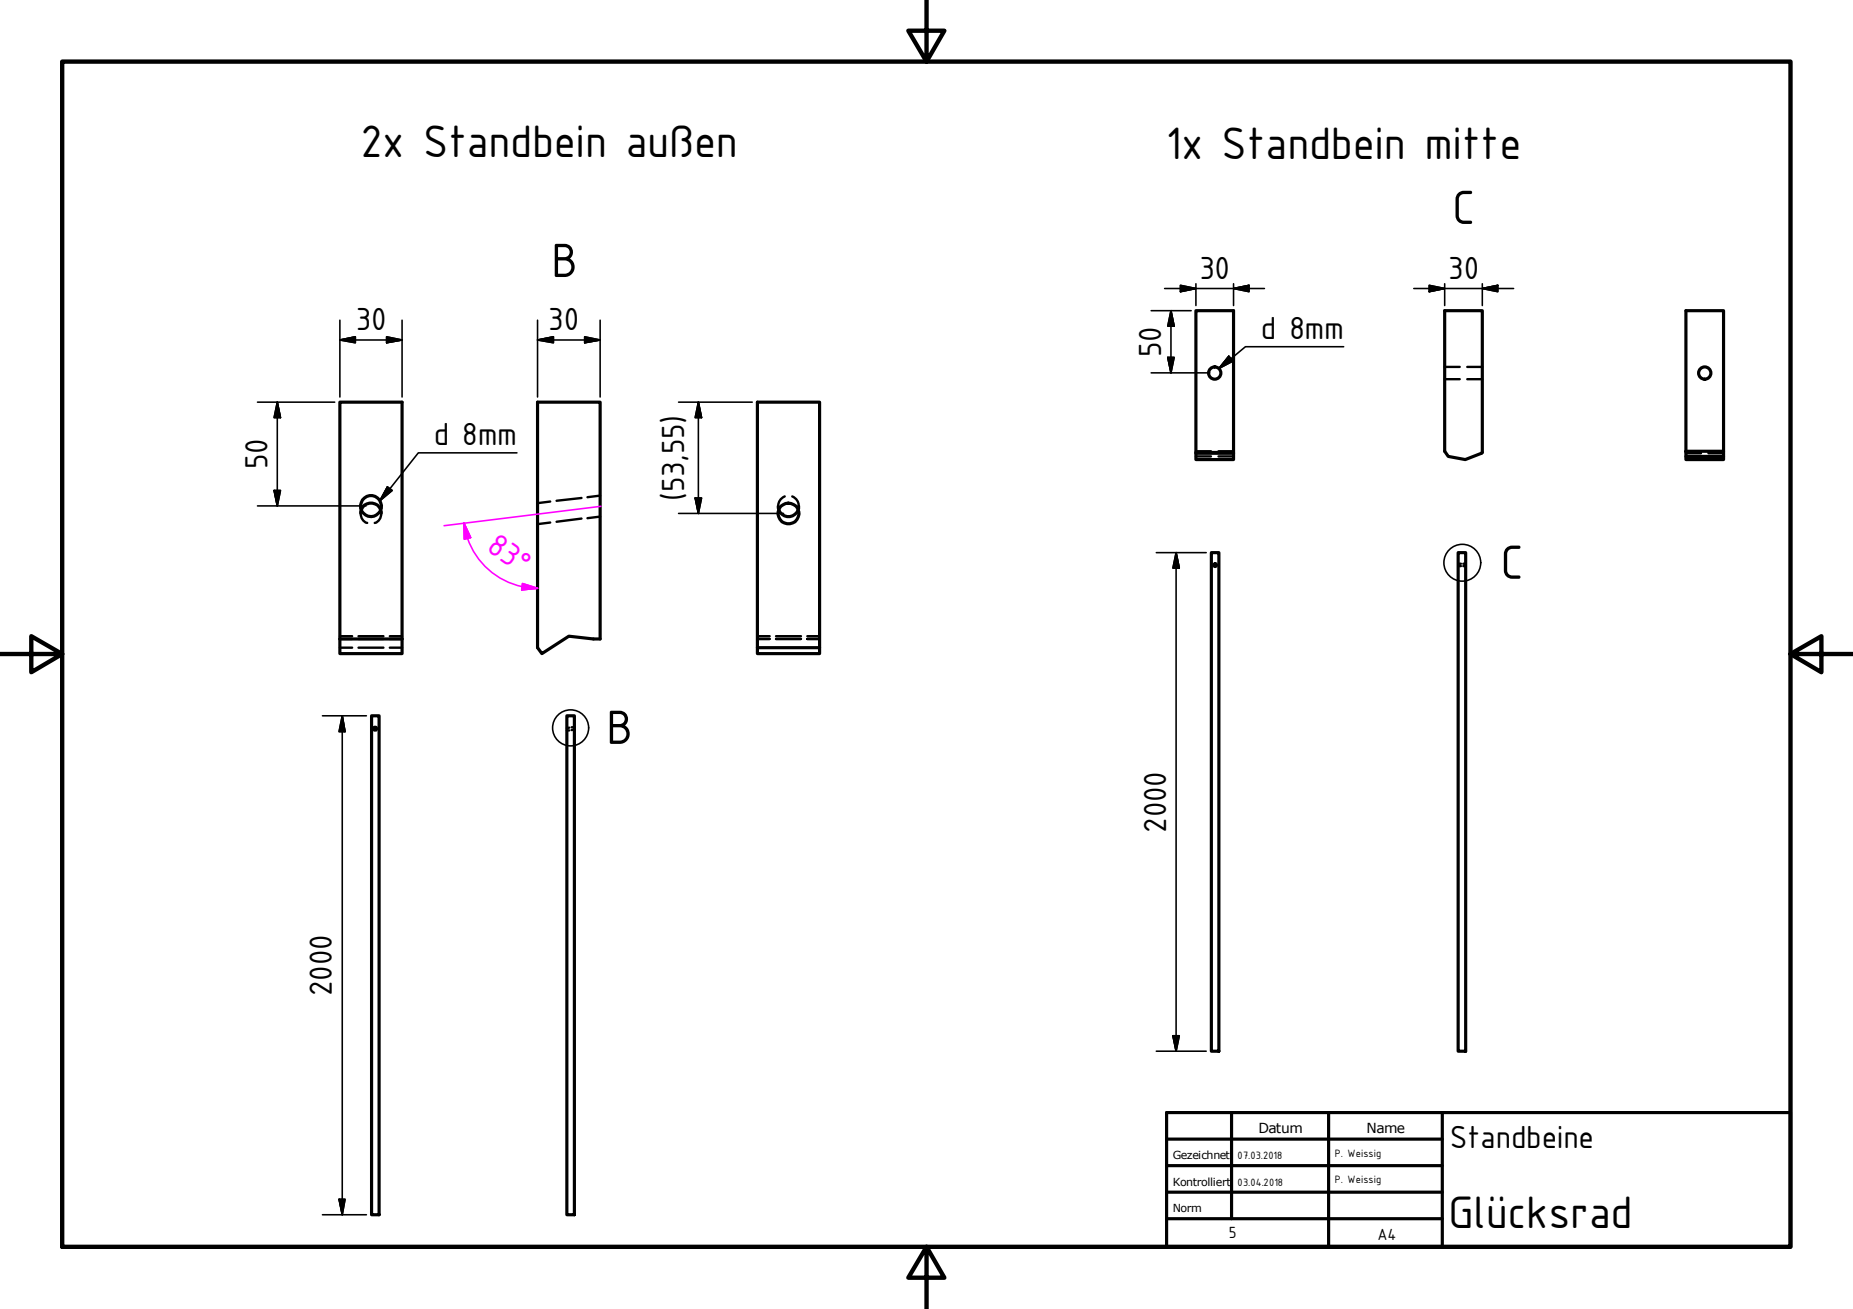
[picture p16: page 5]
2x Standbein auen; 1x Standbein mitte

Datum | Name | Standbeine

Gezeichnet | 07.03.2018 | P. Weissig

Kontrolliert | 03.04.2018 | P. Weissig

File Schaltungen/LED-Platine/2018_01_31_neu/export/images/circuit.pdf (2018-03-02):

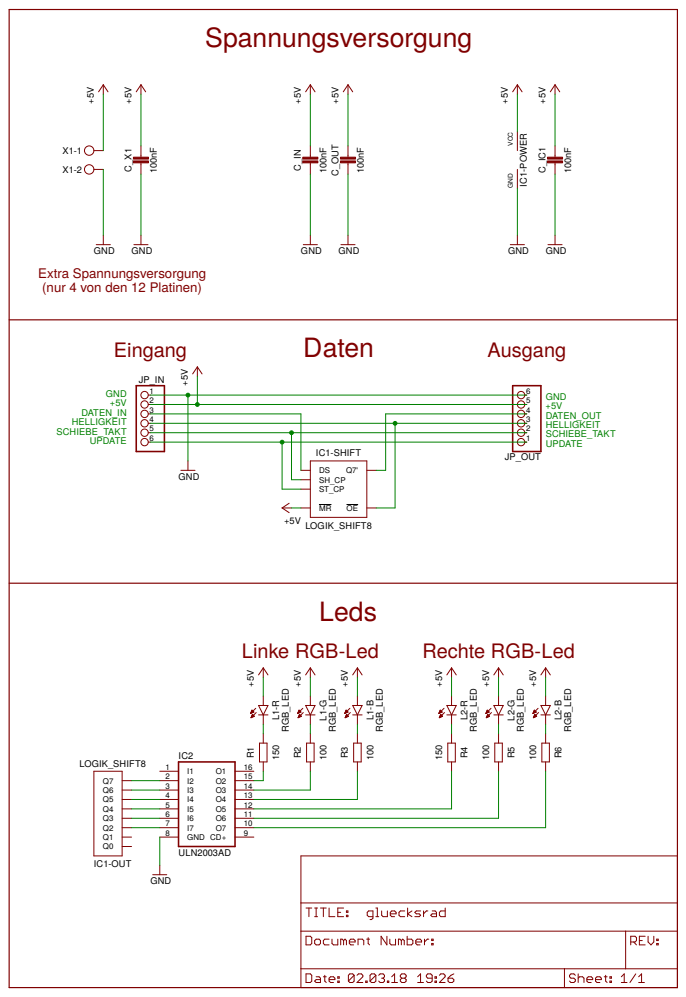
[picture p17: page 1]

Extra Spannungsversorgung
(nur 4 von den 12 Platinen)

3 | 14 O4
4 | 13 O5
5 | 12 O6
6 | 11 O7
7 | 10 CD+

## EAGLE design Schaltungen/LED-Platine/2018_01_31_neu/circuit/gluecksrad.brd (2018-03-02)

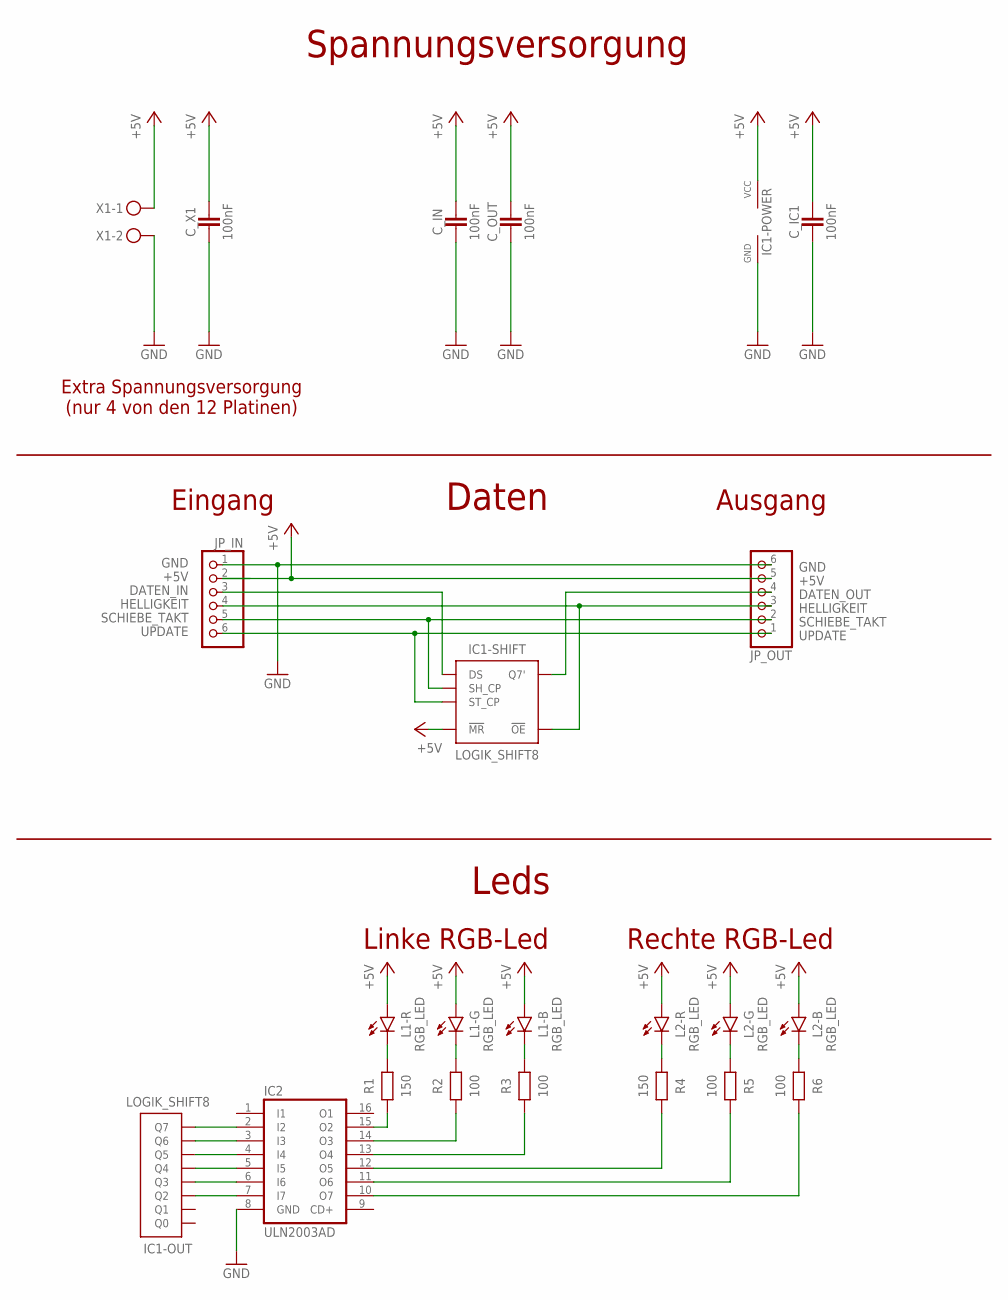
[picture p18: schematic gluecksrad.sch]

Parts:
C_IC1: 100nF; C_THT_2
C_IN: 100nF; C_THT_2
C_OUT: 100nF; C_THT_2
C_X1: 100nF; C_THT_2
IC1: LOGIK_SHIFT8; IC_SOIC16
IC2: ULN2003AD; SO16
JP_IN: PINHD-1X6/90; 1X06/90
JP_OUT: PINHD-1X6/90; 1X06/90
L1, L2: RGB_LED; LED_TOP_PLCC6
R1, R4: 150; R_THT_4
R2, R3, R5, R6: 100; R_THT_4
X1: STECKER_SPG_2

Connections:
+5V: C_IC1.1, C_IN.1, C_OUT.1, C_X1.1, IC1.P$10 (!MR), IC1.P$16 (VCC), JP_IN.2, JP_OUT.5, L1.1 (A), L1.3 (A), L1.4 (A), L2.1 (A), L2.3 (A), L2.4 (A), X1.1
DATEN_IN: IC1.P$14 (DS), JP_IN.3
DATEN_OUT: IC1.P$9 (Q7'), JP_OUT.4
GND: C_IC1.2, C_IN.2, C_OUT.2, C_X1.2, IC1.P$8 (GND), IC2.8 (GND), JP_IN.1, JP_OUT.6, X1.2
HELLIGKEIT: IC1.P$13 (!OE), JP_IN.4, JP_OUT.3
unnamed: IC1.P$5 (Q5), IC2.4 (I4)
unnamed: IC1.P$6 (Q6), IC2.3 (I3)
unnamed: IC1.P$2 (Q2), IC2.7 (I7)
unnamed: IC1.P$7 (Q7), IC2.2 (I2)
unnamed: IC1.P$3 (Q3), IC2.6 (I6)
unnamed: IC2.15 (O2), R1.2
unnamed: IC2.14 (O3), R2.2
unnamed: IC2.13 (O4), R3.2
unnamed: IC2.12 (O5), R4.1
unnamed: IC2.11 (O6), R5.1
unnamed: IC2.10 (O7), R6.1
unnamed: L1.6 (C), R1.1
unnamed: L1.2 (C), R2.1
unnamed: L1.5 (C), R3.1
unnamed: L2.6 (C), R4.2
unnamed: L2.2 (C), R5.2
unnamed: L2.5 (C), R6.2
unnamed: IC1.P$4 (Q4), IC2.5 (I5)
SCHIEBE_TAKT: IC1.P$11 (SH_CP), JP_IN.5, JP_OUT.2
UPDATE: IC1.P$12 (ST_CP), JP_IN.6, JP_OUT.1

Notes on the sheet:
Extra Spannungsversorgung (nur 4 von den 12 Platinen)
Eingang
Ausgang
Daten
Spannungsversorgung
Leds
Linke RGB-Led
Rechte RGB-Led

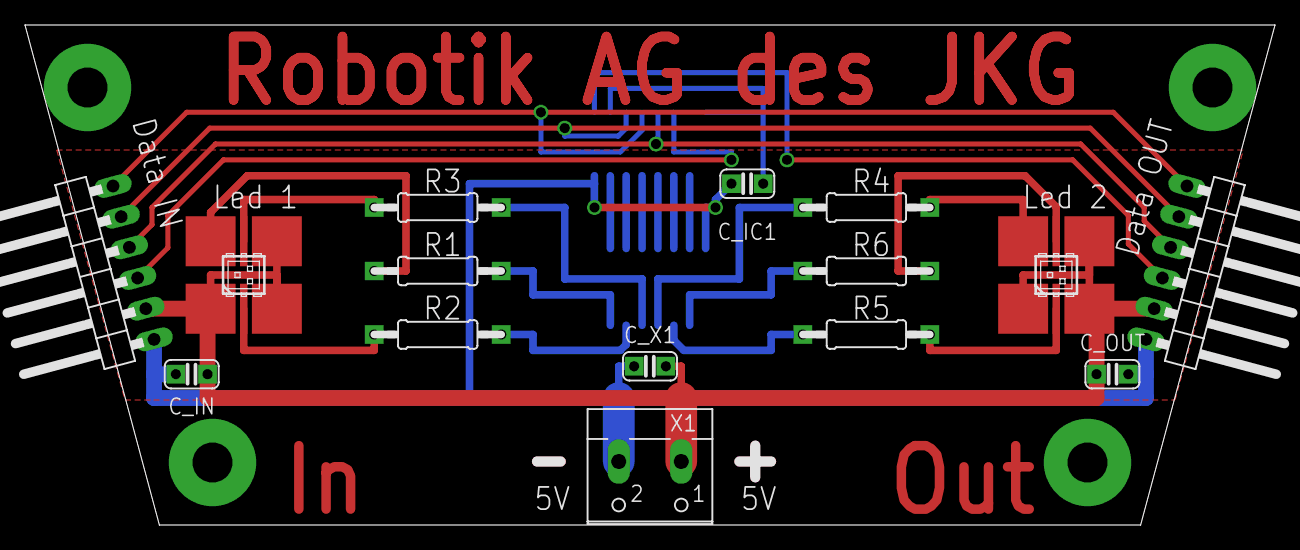
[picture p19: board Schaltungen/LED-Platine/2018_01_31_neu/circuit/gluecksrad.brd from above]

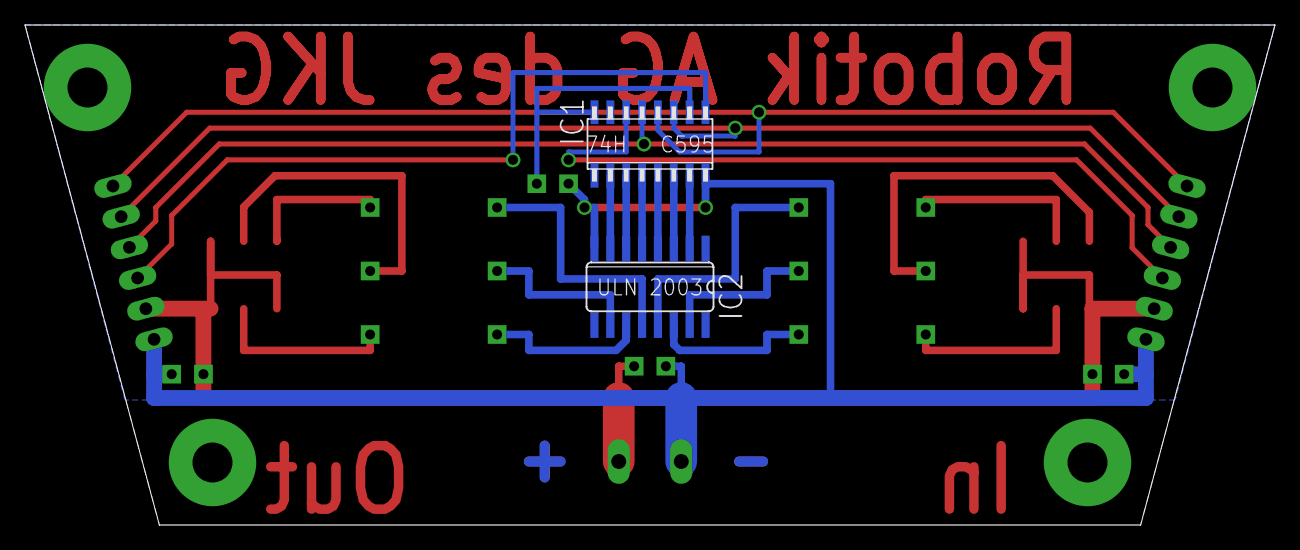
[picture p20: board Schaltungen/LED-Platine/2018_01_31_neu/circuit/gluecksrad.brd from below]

Board: 2 copper layers, 100.0 x 40.0 mm, 17 parts (2 on the bottom side), 25 nets.

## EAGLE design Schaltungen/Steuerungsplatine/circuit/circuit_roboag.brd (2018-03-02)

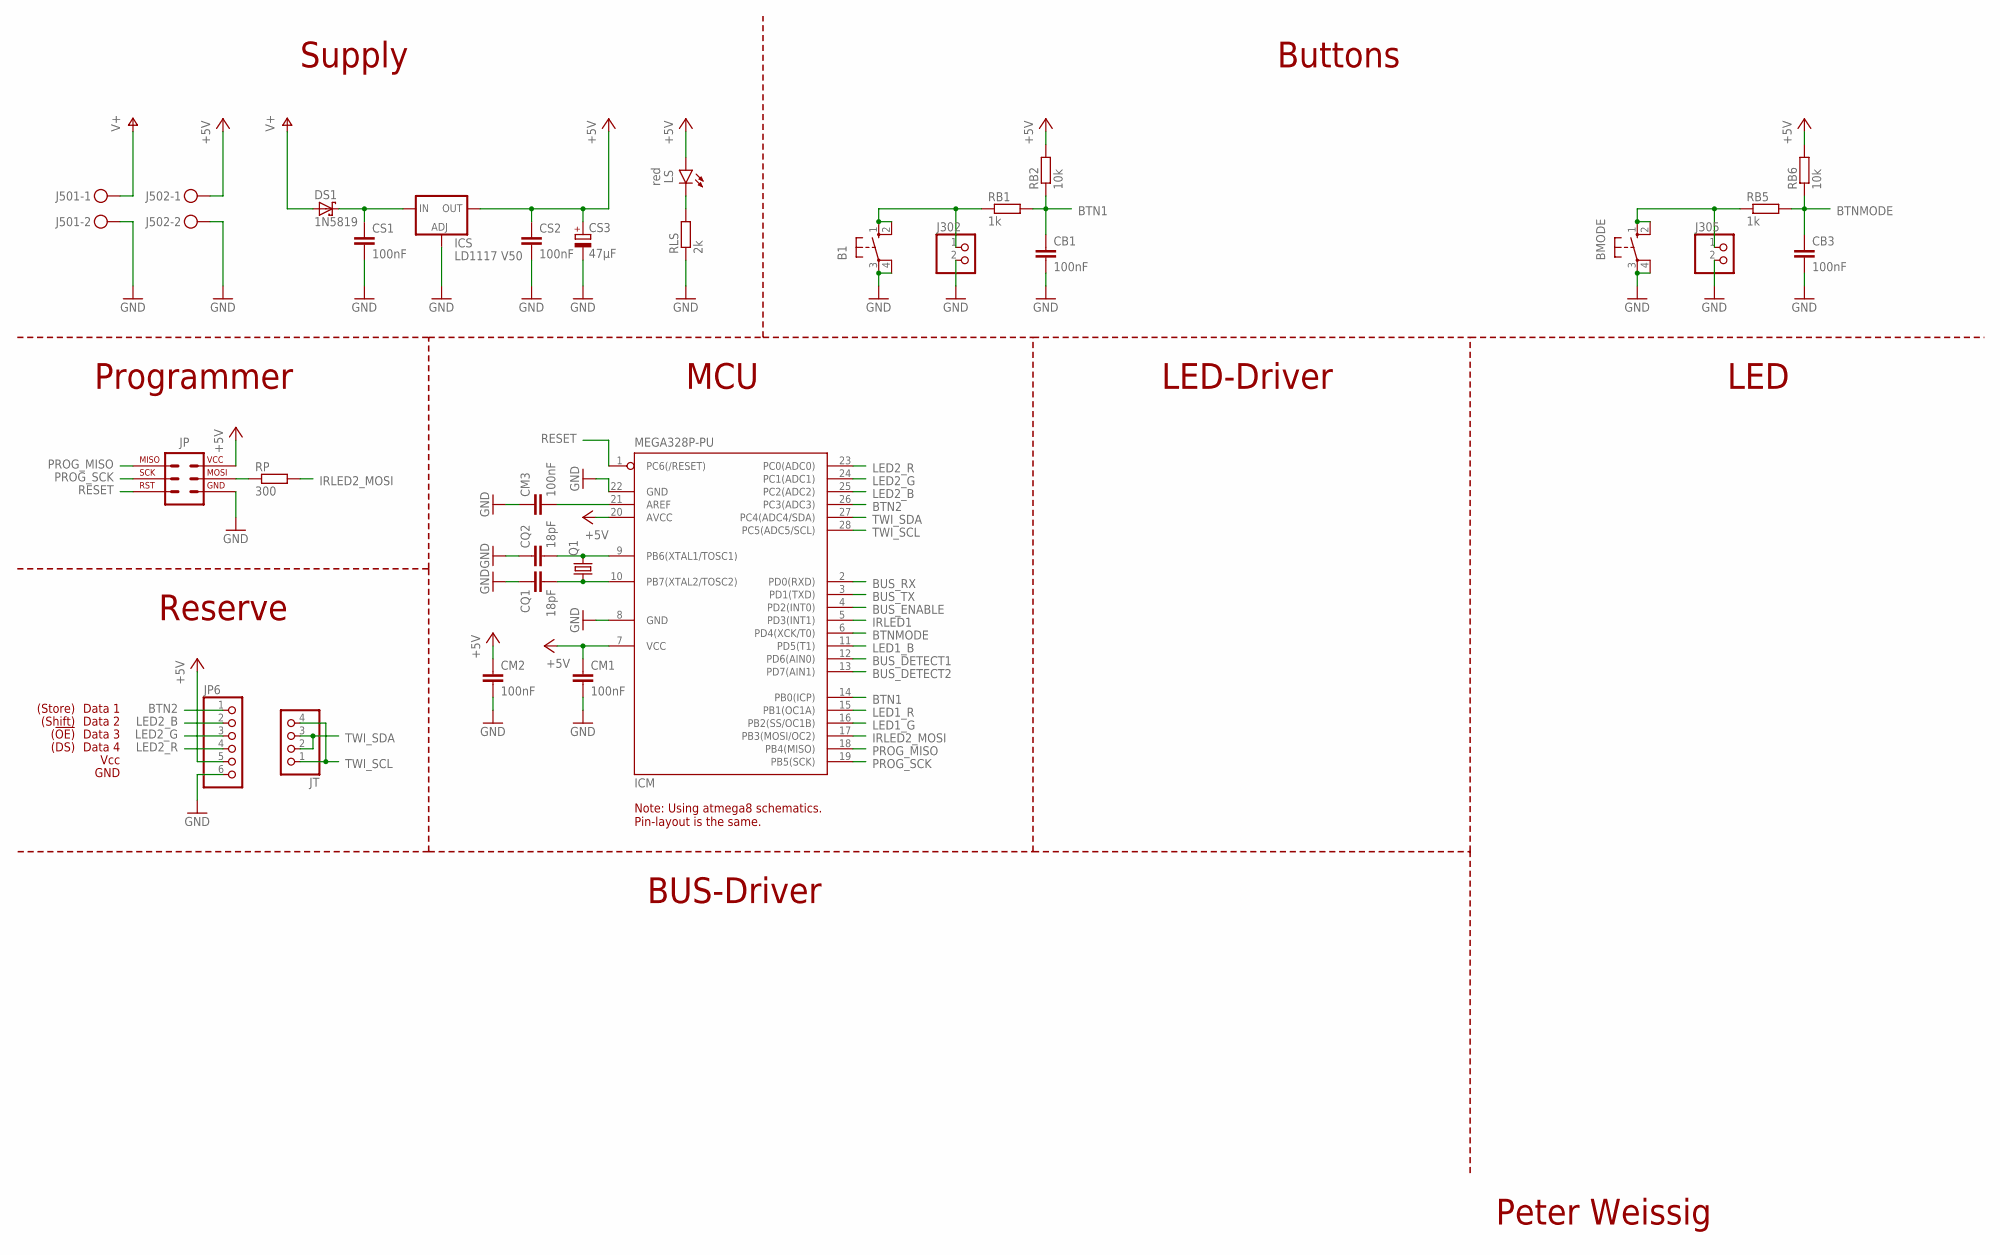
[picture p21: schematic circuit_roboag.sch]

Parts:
B1: 10-XX; B3F-10XX
BMODE: 10-XX; B3F-10XX
CB1, CB3: 100nF; C025-025X050
CM1, CM2, CM3: 100nF; C025-025X050
CQ1, CQ2: 18pF; C025-025X050
CS1, CS2: 100nF; C025-025X050
CS3: 47µF; E2-5
DS1: 1N5819; DO41-7.6
ICM: MEGA328P-PU; DIL28-3
ICS: LD1117 V50; TO220L1
J302, J305: PINHD-1X2; 1X02
J501, J502: STECKER_SPG_2
JP: STECKER_ISP_6; STECKER_WANNE_6
JP6: PINHD-1X6/90; 1X06/90
JT: PINHD-1X4; 1X04
LS: red; LED_3MM
Q1: CRYSTALHC49U70; HC49U70
RB1, RB5: 1k; 0207/10
RB2, RB6: 10k; 0207/10
RLS: 2k; 0207/10
RP: 300; 0207/10

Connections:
+5V: CM1.1, CM2.1, CS2.1, CS3.+, ICM.7 (VCC), ICM.20 (AVCC), ICS.2 (OUT), J502.1, JP.2 (2_VCC), JP6.5, LS.A, RB2.2, RB6.2
BTN1: CB1.1, ICM.14 (PB0(ICP)), RB1.2, RB2.1
BTN2: ICM.26 (PC3(ADC3)), JP6.1
BTNMODE: CB3.1, ICM.6 (PD4(XCK/T0)), RB5.2, RB6.1
BUS_DETECT1: ICM.12 (PD6(AIN0))
BUS_DETECT2: ICM.13 (PD7(AIN1))
BUS_ENABLE: ICM.4 (PD2(INT0))
BUS_RX: ICM.2 (PD0(RXD))
BUS_TX: ICM.3 (PD1(TXD))
GND: B1.3, B1.4 (P1), BMODE.3, BMODE.4 (P1), CB1.2, CB3.2, CM1.2, CM2.2, CM3.1, CQ1.1, CQ2.1, CS1.2, CS2.2, CS3.-, ICM.8 (GND), ICM.22 (GND), ICS.1 (ADJ), J302.2, J305.2, J501.2, J502.2, JP.6 (6_GND), JP6.6, RLS.1
IRLED1: ICM.5 (PD3(INT1))
IRLED2_MOSI: ICM.17 (PB3(MOSI/OC2)), RP.2
LED1_B: ICM.11 (PD5(T1))
LED1_G: ICM.16 (PB2(SS/OC1B))
LED1_R: ICM.15 (PB1(OC1A))
LED2_B: ICM.25 (PC2(ADC2)), JP6.2
LED2_G: ICM.24 (PC1(ADC1)), JP6.3
LED2_R: ICM.23 (PC0(ADC0)), JP6.4
unnamed: B1.1 (S), B1.2 (S1), J302.1, RB1.1
unnamed: CS1.1, DS1.C, ICS.3 (IN)
unnamed: BMODE.1 (S), BMODE.2 (S1), J305.1, RB5.1
unnamed: CQ1.2, ICM.10 (PB7(XTAL2/TOSC2)), Q1.1
unnamed: CQ2.2, ICM.9 (PB6(XTAL1/TOSC1)), Q1.2
unnamed: LS.K (C), RLS.2
unnamed: CM3.2, ICM.21 (AREF)
PROG_MISO: ICM.18 (PB4(MISO)), JP.1 (1_MISO)
PROG_MOSI_1: JP.4 (4_MOSI), RP.1
PROG_SCK: ICM.19 (PB5(SCK)), JP.3 (3_SCK)
RESET: ICM.1 (PC6(/RESET)), JP.5 (5_RST)
TWI_SCL: ICM.28 (PC5(ADC5/SCL)), JT.1, JT.4
TWI_SDA: ICM.27 (PC4(ADC4/SDA)), JT.2, JT.3
V+: DS1.A, J501.1

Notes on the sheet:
Peter Weissig
Supply
Buttons
MCU
Note: Using atmega8 schematics. Pin-layout is the same.
LED-Driver
LED
Reserve
GND
Vcc
(Store)
Data 1
Data 2
Data 3
Data 4
(Shift)
(!OE)
(DS)
Programmer
BUS-Driver

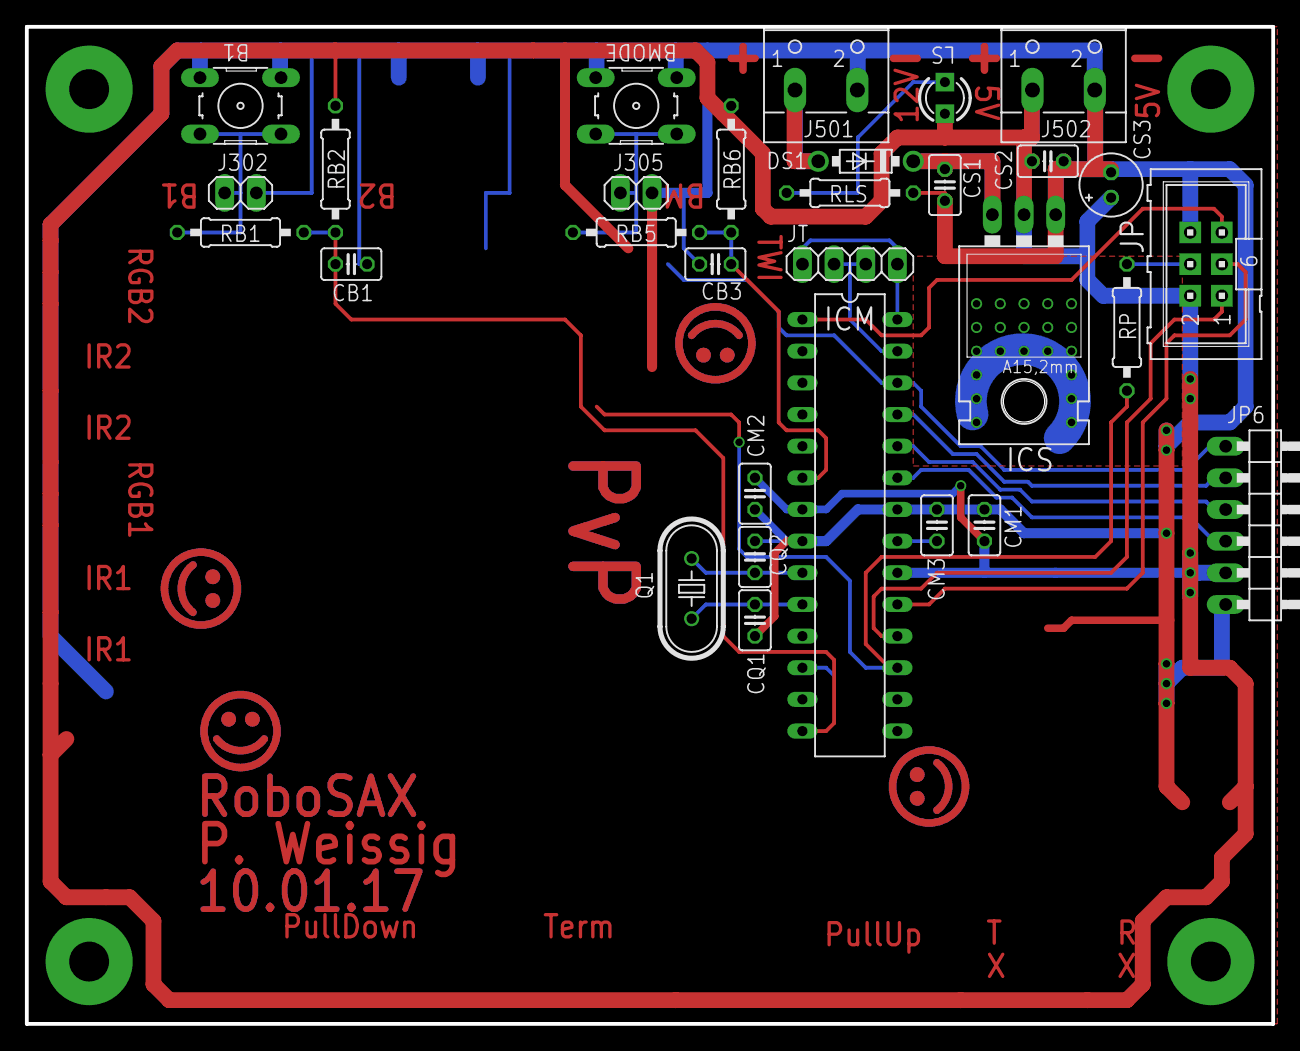
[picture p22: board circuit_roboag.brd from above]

Board: 2 copper layers, 100.0 x 80.0 mm, 30 parts (0 on the bottom side), 23 nets.

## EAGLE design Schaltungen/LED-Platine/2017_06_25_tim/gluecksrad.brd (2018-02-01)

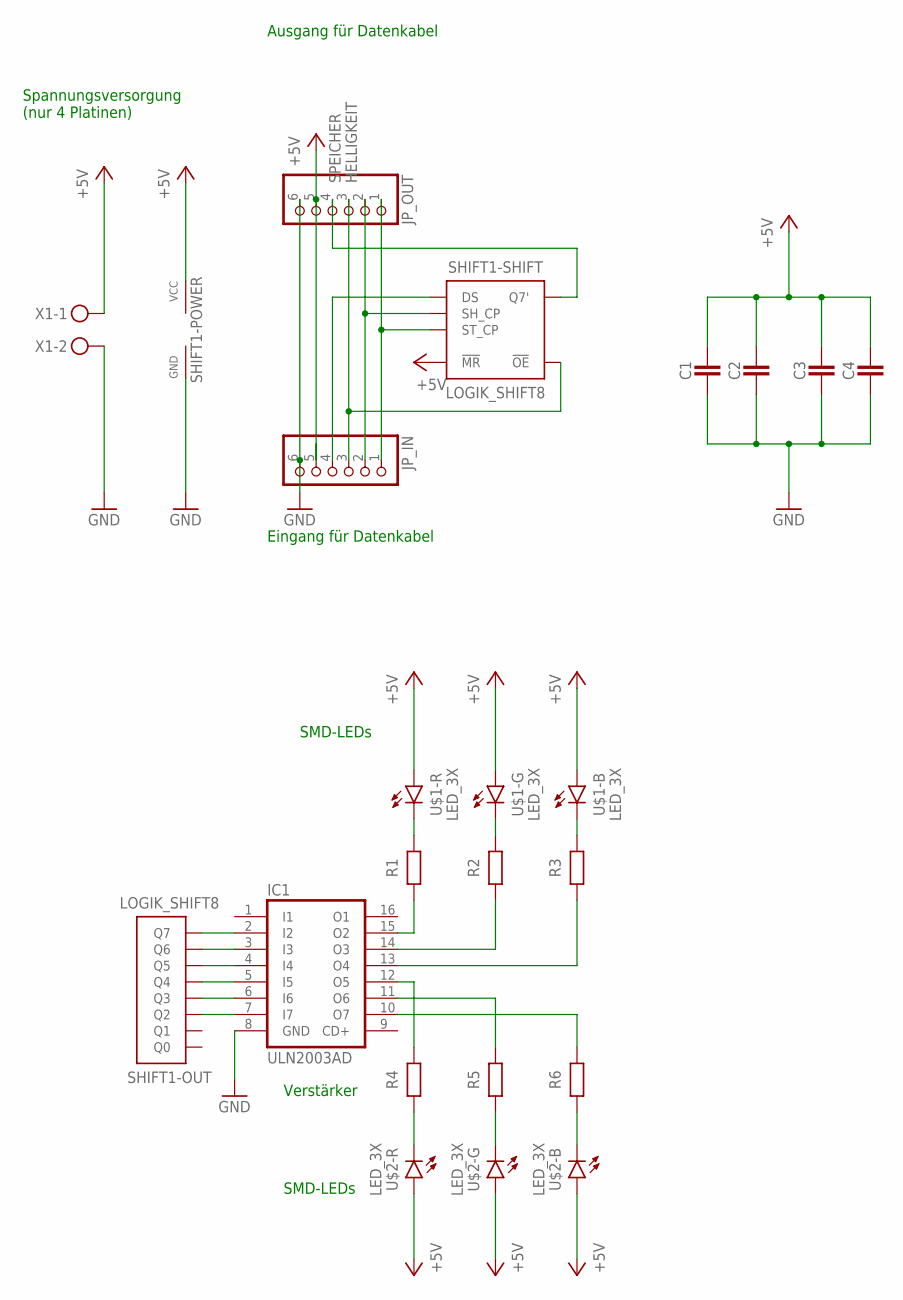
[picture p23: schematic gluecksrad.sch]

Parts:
C1, C3, C4: CAPACITATOR-2,5MM; C_THT_2
C2: CAPACITATOR-5MM; C_THT_3
IC1: ULN2003AD; SO16
JP_IN: PINHD-1X6/90; 1X06/90
JP_OUT: PINHD-1X6/90; 1X06/90
R1, R2, R3, R4, R5, R6: RESISTOR-10MM; R_THT_4
SHIFT1: LOGIK_SHIFT8; IC_SOIC16
U$1, U$2: LED_3X; LED_TOP_PLCC6
X1: STECKER_SPG_2

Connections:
+5V: C1.1, C2.1, C3.1, C4.1, JP_IN.5, JP_OUT.5, SHIFT1.P$10 (!MR), SHIFT1.P$16 (VCC), U$1.1 (A), U$1.3 (A), U$1.4 (A), U$2.1 (A), U$2.3 (A), U$2.4 (A), X1.1
GND: C1.2, C2.2, C3.2, C4.2, IC1.8 (GND), JP_IN.6, JP_OUT.6, SHIFT1.P$8 (GND), X1.2
HELLIGKEIT: JP_IN.3, JP_OUT.3, SHIFT1.P$13 (!OE)
unnamed: IC1.4 (I4), SHIFT1.P$5 (Q5)
unnamed: IC1.3 (I3), SHIFT1.P$6 (Q6)
unnamed: IC1.7 (I7), SHIFT1.P$2 (Q2)
unnamed: IC1.2 (I2), SHIFT1.P$7 (Q7)
unnamed: IC1.6 (I6), SHIFT1.P$3 (Q3)
unnamed: IC1.15 (O2), R1.2
unnamed: IC1.14 (O3), R2.2
unnamed: IC1.13 (O4), R3.2
unnamed: IC1.12 (O5), R4.1
unnamed: IC1.11 (O6), R5.1
unnamed: IC1.10 (O7), R6.1
unnamed: R1.1, U$1.6 (C)
unnamed: R2.1, U$1.2 (C)
unnamed: R3.1, U$1.5 (C)
unnamed: R4.2, U$2.6 (C)
unnamed: R5.2, U$2.2 (C)
unnamed: R6.2, U$2.5 (C)
unnamed: IC1.5 (I5), SHIFT1.P$4 (Q4)
unnamed: JP_OUT.4, SHIFT1.P$9 (Q7')
unnamed: JP_IN.4, SHIFT1.P$14 (DS)
unnamed: JP_IN.2, JP_OUT.2, SHIFT1.P$11 (SH_CP)
SPEICHER: JP_IN.1, JP_OUT.1, SHIFT1.P$12 (ST_CP)

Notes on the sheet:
Spannungsversorgung (nur 4 Platinen)
Eingang für Datenkabel
Ausgang für Datenkabel
SMD-LEDs
Verstärker

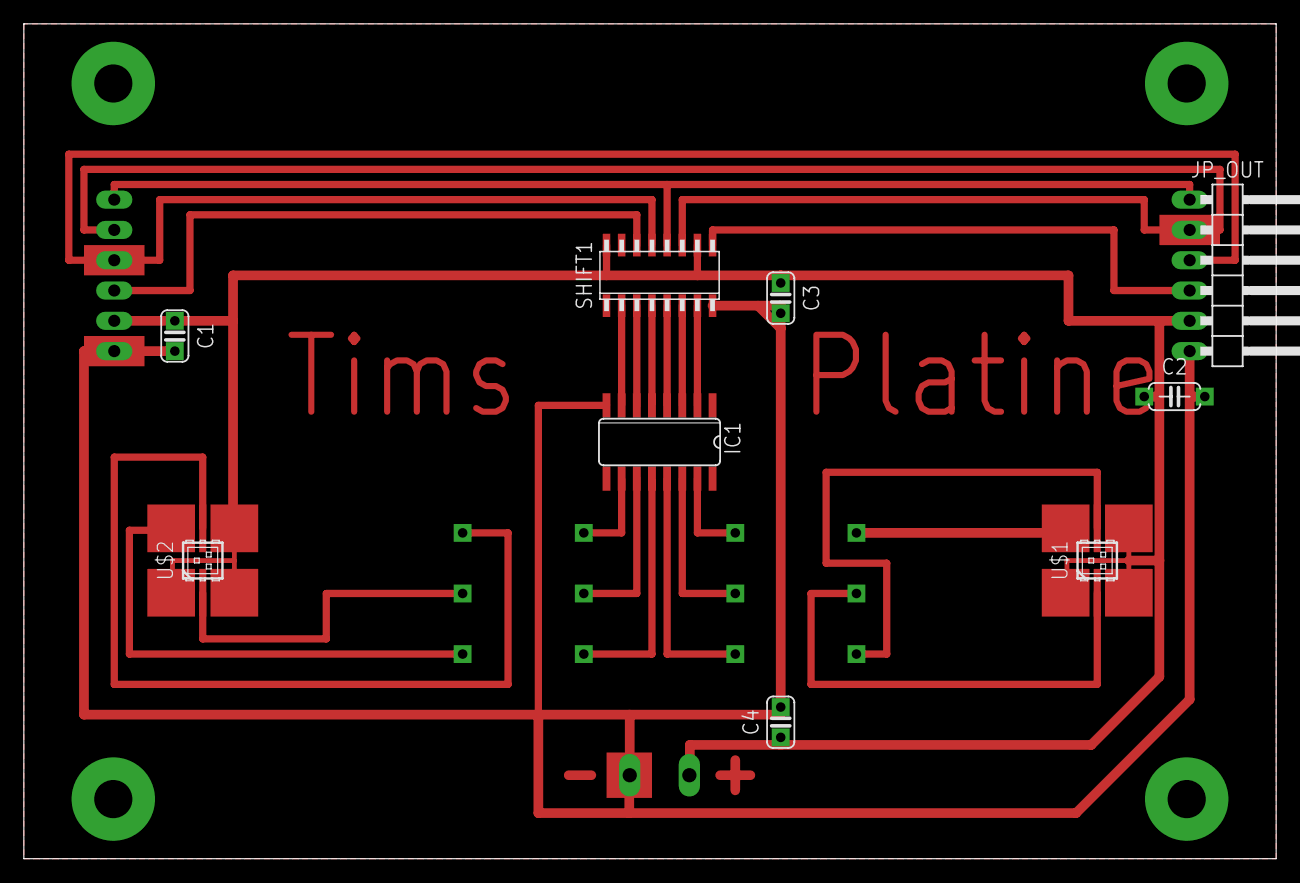
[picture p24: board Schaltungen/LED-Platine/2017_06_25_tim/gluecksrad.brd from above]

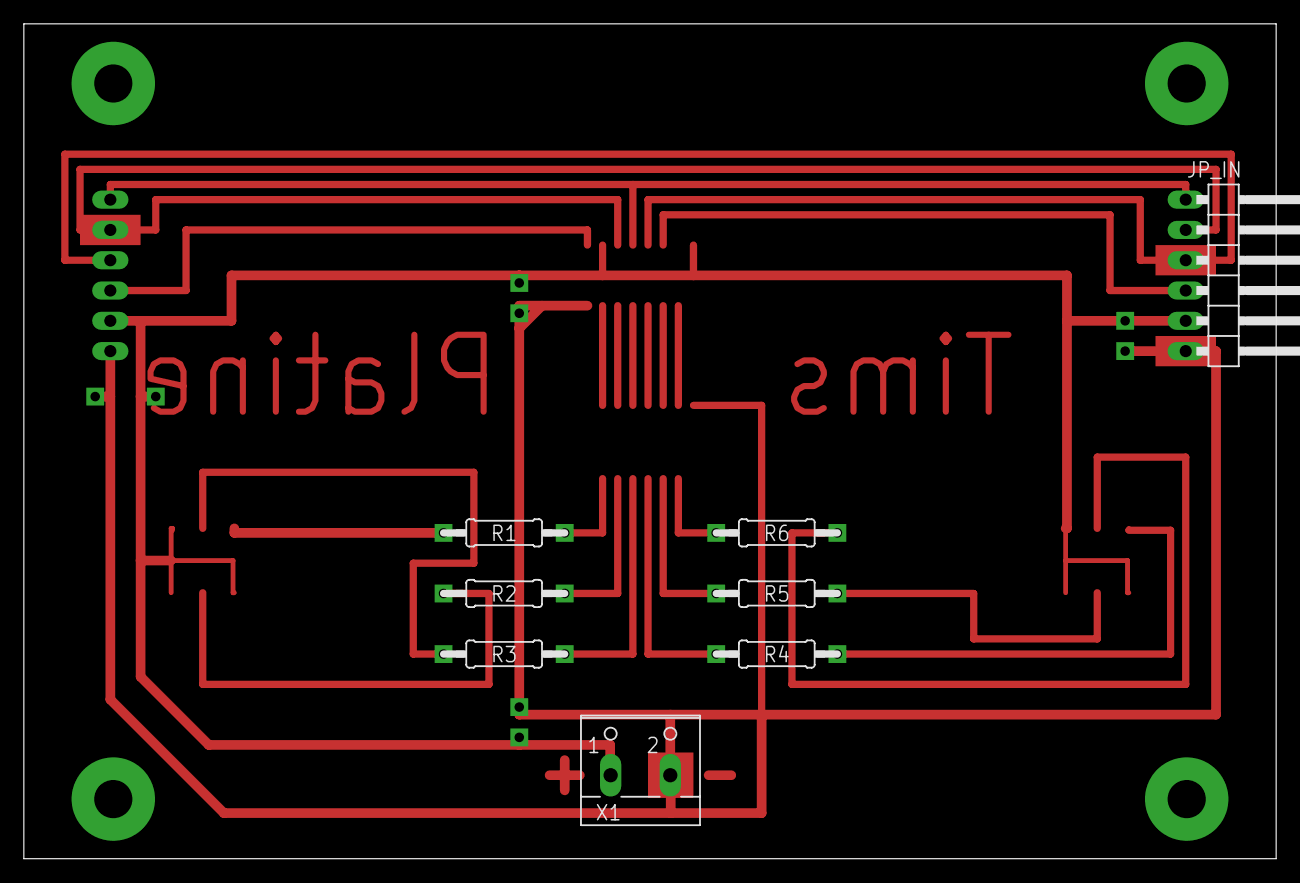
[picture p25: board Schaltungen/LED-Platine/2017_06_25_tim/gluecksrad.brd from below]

Board: 2 copper layers, 105.0 x 70.0 mm, 17 parts (8 on the bottom side), 25 nets.

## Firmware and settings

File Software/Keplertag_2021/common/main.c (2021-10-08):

/*******************************************************************************
* main.c                                                                       *
* ======                                                                       *
*                                                                              *
* Version: 11.0.1                                                              *
* Date   : 04.10.2021                                                          *
* Author : Alexander Feilke, Peter Weissig                                     *
*                                                                              *
* See also:                                                                    *
*   https://github.com/RoboAG/projekt_gluecksrad                               *
*******************************************************************************/



//*********************************<Included files>*****************************
#include <math.h>
#include <avr/io.h>
#include <inttypes.h>

#include "gluecksrad.h"
#include "leds.h"
#include "buttons.h"
#include "systick.h"
#include "random.h"



//*********************************<Flags>**************************************
#define MODE_DEFAULT           1
#define MODE_COUNTDOWN         2

#define STATE_DEMO             0
#define STATE_ROTATING         1
#define STATE_ROTATE_FINISH    2
#define STATE_PRICE            3
#define STATE_PRICE_STOPPING   4
#define STATE_MENU_STARTING    5
#define STATE_MENU             6
#define STATE_MENU_NEXT        7
#define STATE_MENU_SELECTING   8
#define STATE_MENU_SELECTED    9
//#define STATE_SHOW_PRICES     10
#define STATE_RESET_PRICES    11
#define STATE_PRICES_EMPTY    12
#define STATE_EEPROM_INVALID  13

#define MENU_EXIT              0
#define MENU_MODE_DEFAULT      1
#define MENU_MODE_COUNTDOWN    2
//#define MENU_SHOW_PRICES       3
#define MENU_EEPROM_RESET      3
#define MENU_COUNT             4

// wheel mode
uint8_t mode  = MODE_DEFAULT;         // will be overriden during
                                      // gluecksrad_init()

// program state
uint8_t state = STATE_EEPROM_INVALID; // will be overriden during
                                      // gluecksrad_init()

// menu state
uint8_t menu  = MENU_EXIT;            // will be overriden during
                                      // start of menu



//*********************************<Constants>**********************************
// #define VERSION        --> see wrapper files "wrapper.c"
#define EEPROM_KEY (0xA760 + VERSION)

// #define PRICES_COUNT 5 --> see wrapper files "wrapper.c"
// #define PRICES_MAX     --> see wrapper files "wrapper.c"

#define ROT_VEL 80


#define MENU_INIT_DELAY           1000
#define MENU_PRICE_DELAY           500
#define MENU_RESET_DELAY          3000

#define MENU_START_MINDELAY       1000
#define MENU_START_MAXDELAY       3000

#define MENU_NEXT_MINDELAY          50
#define MENU_NEXT_DELAY            200
#define MENU_SELECT_MINDELAY       500
#define MENU_SELECT_MAXDELAY      3000

#define ANIMATE_PRICES_EMPTY_LOOP 4000


#define EEPROM_ADR_KEY1             0x20
#define EEPROM_ADR_MODE             0x22
#define EEPROM_ADR_PRICE_COUNT      0x23
#define EEPROM_ADR_PRICES_MAX_START 0x30
#define EEPROM_ADR_PRICES_START     0x40
#define EEPROM_ADR_KEY2             0x50


const struct sLed menu_colors[MENU_COUNT] = {
    {        0,        0, LEDS_MAX },
    {        0, LEDS_MAX,        0 },
    { LEDS_MAX, LEDS_MAX,        0 },
    { LEDS_MAX,        0,        0 }
};

// const ... price_colors[PRICES_COUNT] --> see wrapper files "wrapper.c"

//array of maximum number of prices
const int16_t prices_max[PRICES_COUNT] = PRICES_MAX;



//*********************************<Macros>*************************************
#define eeprom_read_uint8()      eeprom_read()
#define eeprom_write_uint8(data) eeprom_write(data)

#define getPriceColor(i) price_colors[i]
#define getLedColor(i) price_colors[getLedPrice(i)]

#define getMenuColor(i) menu_colors[i]
#define getLedMenu(i) ((i)*MENU_COUNT/LEDS_COUNT)
#define getLedMenuColor(i) menu_colors[getLedMenu(i)]



//*********************************<Prototypes>*********************************
float   abs_float              (float v);

void    updateTime             (void);


// uint8_t getLedPrice         (uint8_t i); --> see wrapper files "wrapper.c"
void    prices_clear           (void);
void    prices_set_default     (void);
void    prices_update_sum      (void);

void    eeprom_reset           (void); // overriding eeprom
uint8_t eeprom_check           (void); // only reading eeprom
uint8_t eeprom_load            (void); // checks the eeprom first
                                       // afterwards, loads mode & prices
uint8_t eeprom_save_mode                 (void); // checks the eeprom first
void    eeprom_save_prices_without_check (void); // no check is done!

void    gluecksrad_init        (void);
void    setMode                (uint8_t md); // switches to the correct state
                                             // (doesn't save to eeprom)
void    setState               (uint8_t st);

uint8_t _getRotationTarget     (void); // internal helper function
void    setRotationTarget      (void);

void    handleButtons          (void);
void    updateStateMachine     (void);

void    animate                (void);

int     main                   (void);



//*********************************<Math>***************************************
float abs_float (float v)
{
    if (v > 0)
        return v;
    else
       return -v;
}



//*********************************[time]***************************************
// 32-bit timer in milliseconds -> overflow after: 49d 17h 2m 47s 296ms
uint32_t time_now = 0,  time_last = 0;

// time when Mode-Button press started
uint32_t time_btnMode_start = 0;

// time when the current state started
uint32_t time_state_start;


void updateTime (void)
{
    time_last = time_now;
    time_now = systick_get();
}



//*********************************[prices]*************************************
//array of current number of prices
int16_t prices[PRICES_COUNT];

//sum of available prices
int16_t price_sum = 0;


// uint8_t getLedPrice (uint8_t i) --> see wrapper files "wrapper.c"

void prices_clear (void)
{
    price_sum = 0;
    for (uint8_t i = 0; i < PRICES_COUNT; i++)
    {
        prices[i] = 0;
    }
}

void prices_set_default (void)
{
    price_sum = 0;
    for (uint8_t i = 0; i < PRICES_COUNT; i++)
    {
        prices[i]  = prices_max[i];
        price_sum += prices_max[i];
    }
}

void prices_update_sum (void)
{
    price_sum = 0;
    for (uint8_t i = 0; i < PRICES_COUNT; i++)
    {
        price_sum += prices[i];
    }
}



//*********************************[eeprom]*************************************
/* EEPROM usage
 *
 * 0x20-0x21  EEPROM_KEY
 * 0x22       Mode
 * 0x23       PRICES_COUNT
 * 0x24-0x2F  (reserved)
 * 0x30-0x31  prices_max[0]
 * 0x32-0x33  prices_max[1]
 * ...
 * 0x40-0x41  prices[0]
 * 0x42-0x43  prices[1]
 * ...
 * 0x50-0x51  EEPROM_KEY
 */


// reset the EEPROM
void eeprom_reset (void)
{
    eeprom_adress_set(EEPROM_ADR_KEY1);
    eeprom_write_uint16(EEPROM_KEY);
    eeprom_write_uint16(EEPROM_KEY);


    // write initial EEPROM_KEY
    eeprom_adress_set(EEPROM_ADR_KEY1);
    eeprom_write_uint16(EEPROM_KEY);

    // write final EEPROM_KEY
    eeprom_adress_set(EEPROM_ADR_KEY2);
    eeprom_write_uint16(EEPROM_KEY);

    // write mode
    eeprom_adress_set(EEPROM_ADR_MODE);
    eeprom_write_uint8(mode);

    // write PRICES_COUNT
    eeprom_adress_set(EEPROM_ADR_PRICE_COUNT);
    eeprom_write_uint8(PRICES_COUNT);

    // write prices_max
    eeprom_adress_set(EEPROM_ADR_PRICES_MAX_START);
    for (uint8_t i = 0; i < PRICES_COUNT; i++)
    {
        eeprom_write_uint16(prices_max[i]);
    }

    // write prices
    eeprom_adress_set(EEPROM_ADR_PRICES_START);
    for (uint8_t i = 0; i < PRICES_COUNT; i++)
    {
        eeprom_write_uint16(prices[i]);
    }
}

// check the EEPROM for
//    programm version,
//    the price count,
//    the maximum number of prices and
//    the range of the stored prices
uint8_t eeprom_check (void)
{
    // check initial EEPROM_KEY
    eeprom_adress_set(EEPROM_ADR_KEY1);
    if (eeprom_read_uint16() != EEPROM_KEY) return 0;

    // check final EEPROM_KEY
    eeprom_adress_set(EEPROM_ADR_KEY2);
    if (eeprom_read_uint16() != EEPROM_KEY) return 0;

    // check mode
    eeprom_adress_set(EEPROM_ADR_MODE);
    uint8_t temp_mode = eeprom_read_uint8();
    if ((temp_mode == 0) || (temp_mode > 2)) return 0;

    // check PRICES_COUNT
    eeprom_adress_set(EEPROM_ADR_PRICE_COUNT);
    if (eeprom_read_uint8() != PRICES_COUNT) return 0;

    // check prices_max
    eeprom_adress_set(EEPROM_ADR_PRICES_MAX_START);
    for (uint8_t i = 0; i < PRICES_COUNT; i++)
    {
        if (eeprom_read_uint16() != prices_max[i]) return 0;
    }

    // check ranges of prices
    eeprom_adress_set(EEPROM_ADR_PRICES_START);
    int16_t temp_price;
    for (uint8_t i = 0; i < PRICES_COUNT; i++)
    {
        temp_price = (int16_t) eeprom_read_uint16();
        if ((temp_price < 0) || (temp_price > prices_max[i])) return 0;
    }

    // all fine :-)
    return 1;
}

// load content (mode & prices) from EEPROM
uint8_t eeprom_load (void)
{
    if (! eeprom_check())
        return 0;

    // load mode
    eeprom_adress_set(EEPROM_ADR_MODE);
    mode = eeprom_read_uint8();
    // check again!
    if ((mode == 0) || (mode > 2)) return 0;

    // load prices
    price_sum = 0;
    eeprom_adress_set(EEPROM_ADR_PRICES_START);
    int16_t temp;
    for (uint8_t i = 0; i < PRICES_COUNT; i++)
    {
        temp = (int16_t) eeprom_read_uint16();
        // check again!
        if ((temp < 0) || (temp > prices_max[i]))
            return 0;

        // store prices
        prices[i] = temp;
        // calculate sum
        price_sum += prices[i];
    }
    return 1;
}

// save current mode to EEPROM, if possible
uint8_t eeprom_save_mode (void)
{
    if (!eeprom_check())
    {
        return 0;
    }

    eeprom_adress_set(EEPROM_ADR_MODE);
    eeprom_write_uint8(mode);

    return 1;
}

// save current prices to EEPROM - no EEPROM check is done!
void eeprom_save_prices_without_check (void)
{
    if (mode == MODE_COUNTDOWN)
    {
        // write prices
        eeprom_adress_set(EEPROM_ADR_PRICES_START);
        for (uint8_t i = 0; i < PRICES_COUNT; i++)
        {
            eeprom_write_uint16(prices[i]);
        }
    }
}



//*********************************[init]***************************************
// initialize program
void gluecksrad_init (void)
{
    leds_init();
    robolib_init();
    leds_clearAll();
    systick_init();
    random_init();

    // load current mode (& price list)
    if (eeprom_load()) {

        // show current mode on startup
        if (mode == MODE_COUNTDOWN)
            leds_setAll2(getMenuColor(MENU_MODE_COUNTDOWN));
        else if (mode == MODE_DEFAULT)
            leds_setAll2(getMenuColor(MENU_MODE_DEFAULT  ));
        else // this should never happen ...
            leds_setAll(LEDS_MAX, 0, LEDS_MAX); // purple

        // switch to the correct mode afterwards
        //   (this will set the correct state & may init the prices)
        setMode(mode);
    } else {
        // show error on startup
        leds_setAll(LEDS_MAX, 0, 0); // full red

        // switch to default mode afterwards
        setMode(MODE_DEFAULT);
    }

    systick_delay(MENU_INIT_DELAY);
    updateTime();
}



//*********************************[setMode]************************************
void setMode (uint8_t md)
{
    mode = md;

    switch (md)
    {
        case MODE_DEFAULT:
        {
            prices_set_default();
            setState(STATE_DEMO);
        }
        break;

        case MODE_COUNTDOWN:
        {
            prices_update_sum();
            if (price_sum <= 0)
                setState(STATE_PRICES_EMPTY);
            else
                setState(STATE_DEMO);
        }
        break;
    }
}



//*********************************[setState]***********************************
void setState (uint8_t st)
{
    state = st;
    time_state_start = time_now;
}



//*********************************[setRotationTarget]**************************
// rotation target
uint16_t rot_target_abs; // absolute target including rounds
uint8_t  rot_target;     // target led (0-20]

// rotation acceleration and time
float rot_acc, rot_time;


// internal helper function
uint8_t _getRotationTarget (void)
{
    if (price_sum <= 0) return 0;

    // choose random price
    uint16_t i, num = random(), ran = num % price_sum;
    uint8_t cat;

    // select category dependent on the probability
    for (cat = 0; cat < PRICES_COUNT && ran >= prices[cat]; cat++)
        ran -= prices[cat];

    #define TARGET_STEP 3
    num = LEDS_COUNT * TARGET_STEP + num % 20;

    for (i = num % 20; i < num; i += TARGET_STEP)
        if (getLedPrice(i % 20) == cat)
            return i % 20;

    return 0;
}

void setRotationTarget (void)
{

    rot_target = _getRotationTarget();

    uint16_t rounds = 2 * (14 + getLedPrice(rot_target)) * (15 + (time_now % 5)) / 39;
    rot_target_abs = rounds * 20 + rot_target;
    rot_acc = - ROT_VEL * ROT_VEL / (float)(2 * (rot_target_abs) + 1);
    rot_time = 1000.0 * abs_float(ROT_VEL / rot_acc);
}



//**********************************[handleButtons]*****************************
uint8_t btnMode          = 0; // current state as boolean
uint8_t btnMode_released = 0; // boolean flag for falling flank
uint8_t bumper  = 0; // current state as boolean

void handleButtons (void)
{
    bumper  = buttons_getBumper();

    uint8_t btnMode_previous = btnMode;
    btnMode = buttons_getMode();
    btnMode_released = btnMode_previous && !btnMode;

    if (btnMode)
    {
        if ((!btnMode_previous) || (time_btnMode_start == 0))
            time_btnMode_start = time_now;
    } else {
        // in case of release, delay clearing of start time by one cycle
        if (!btnMode_released)
            time_btnMode_start = 0;
    }
}



//**********************************[updateStateMachine]************************
void updateStateMachine (void)
{
    uint32_t diff_state   = time_now - time_state_start;
    uint32_t diff_btnMode = 0;
    if (time_btnMode_start)
        diff_btnMode = time_now - time_btnMode_start;

    switch (state)
    {
        case STATE_DEMO:
        {
            if (diff_btnMode > MENU_START_MINDELAY)
                setState(STATE_MENU_STARTING);
            else if (bumper)
            {
                if (price_sum > 0)
                {
                    setRotationTarget();
                    setState(STATE_ROTATING);
                }
                else
                    setState(STATE_PRICES_EMPTY);
            }
        }
        break;

        case STATE_ROTATING:
        {
            if (diff_state >= rot_time)
            {
                if (mode == MODE_COUNTDOWN)
                {
                    prices[getLedPrice(rot_target)]--;
                    prices_update_sum();
                    eeprom_save_prices_without_check();
                }

                setState(STATE_ROTATE_FINISH);
            }
        }
        break;

        case STATE_ROTATE_FINISH:
        {
            if (diff_state >= MENU_PRICE_DELAY)
                setState(STATE_PRICE);
        }
        break;

        case STATE_PRICE:
        {
            if (btnMode)
            {
                setState(STATE_PRICE_STOPPING);
            }

        }
        break;
        case STATE_PRICE_STOPPING:
        {
            if (btnMode_released)
            {
                if (price_sum > 0)
                    setState(STATE_DEMO);
                else
                    setState(STATE_PRICES_EMPTY);
            }
        }

        case STATE_MENU_STARTING:
        {
            if (btnMode_released)
            {
                if (diff_btnMode >= MENU_START_MAXDELAY)
                {
                    setState(STATE_MENU);
                    menu = MENU_EXIT;
                } else {
                    if (price_sum > 0)
                        setState(STATE_DEMO);
                    else
                        setState(STATE_PRICES_EMPTY);
                }
            }
        }
        break;

        case STATE_MENU:
        {
            if (diff_btnMode >= MENU_SELECT_MINDELAY)
                setState(STATE_MENU_SELECTING);
            else if (btnMode_released && (diff_btnMode >= MENU_NEXT_MINDELAY))
                setState(STATE_MENU_NEXT);
        }
        break;

        case STATE_MENU_NEXT:
        {
            if (diff_state > MENU_NEXT_DELAY)
            {
                setState(STATE_MENU);
                menu = (menu + 1) % MENU_COUNT;
            }
        }
        break;

        case STATE_MENU_SELECTING:
        {
            if (diff_btnMode >= MENU_SELECT_MAXDELAY)
                setState(STATE_MENU_SELECTED);
            else if (!btnMode)
                setState(STATE_MENU);
        }
        break;

        case STATE_MENU_SELECTED:
        {
            if (btnMode_released)
            {
                switch (menu)
                {
                    case MENU_EXIT:
                    {
                        if (price_sum > 0)
                            setState(STATE_DEMO);
                        else
                            setState(STATE_PRICES_EMPTY);
                    }
                    break;

                    case MENU_MODE_DEFAULT:
                    {
                        setMode(MODE_DEFAULT);
                        if (!eeprom_save_mode())
                            setState(STATE_EEPROM_INVALID);
                        else
                            setState(STATE_DEMO);
                    }
                    break;

                    case MENU_MODE_COUNTDOWN:
                    {
                        mode = MODE_COUNTDOWN; // needed for eeprom_save_mode()
                        if (!eeprom_save_mode() || !eeprom_load())
                        {
                            setMode(MODE_COUNTDOWN); // sets mode in case of
                                                     // error
                            setState(STATE_EEPROM_INVALID);
                        } else
                            setMode(MODE_COUNTDOWN); // selects between DEMO
                                                     // and PRICES_EMPTY
                    }
                    break;
/*
                    case MENU_SHOW_PRICES:
                    {
                        setState(STATE_SHOW_PRICES);
                    }
                    break;
*/
                    case MENU_EEPROM_RESET:
                    {
                        //reset price array
                        prices_set_default();

                        //reset eeprom
                        eeprom_reset();

                        // switch to current mode (changes state)
                        setMode(mode);
                    }
                    break;
                }
            }
        }
        break;
/*
        case STATE_SHOW_PRICES:
        {
            if (bumper)
            {
                setState(STATE_MENU);
            }
        }
        break;
*/
        case STATE_PRICES_EMPTY:
        {
            if (diff_btnMode > MENU_START_MINDELAY)
                setState(STATE_MENU_STARTING);
        }
        break;

        case STATE_EEPROM_INVALID:
        {
            if (btnMode_released && (diff_btnMode > MENU_RESET_DELAY))
            {
                //reset price array
                prices_set_default();

                //reset eeprom
                eeprom_reset();

                // switch to current mode (changes state)
                setMode(mode);
            }
        }
        break;
    }
}
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
int main (void)
{
    // initialize
    gluecksrad_init();


    // main loop
    while (1)
    {
        updateTime();

        handleButtons();
        updateStateMachine();

        animate();
    }

    return 0;
}

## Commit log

2018-02-01 adeed circuit files (made with eagle)
    [gluecksrad.GBL, gluecksrad.GBO, gluecksrad.GBP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]
2018-02-17 added picture of principal arrangement of circuit boards
2018-03-02 updated LED-Platine (added values for resistors)
    [gluecksrad.brd, gluecksrad.sch]
2018-03-02 moved circuit for LED-Platine to dedicated subfolder
    [gluecksrad.GBL, gluecksrad.GBO, gluecksrad.GBP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]
2018-03-02 added Steuerungsplatine (copy from https://github.com/RoboSAX/eagle_licht.git)
    [circuit_roboag.brd, circuit_roboag.sch, parts_roboag.ods]
2018-03-02 updated LED-Platine (resistor for red is 150R not 120R)
    [gluecksrad.brd, gluecksrad.sch]
2018-03-07 added Gedanken zur Platinenanzahl (10 scheint optimal)
    [anzahl_platinen.ods]
2018-03-18 added second LED API variant
2018-03-18 updated led_api 1
2018-03-18 added button test
2018-03-19 fixed led api 1
    bug: board order 2-1 instead of 1-2 (2-1-4-3-6-5-8-7)
2018-03-19 changed button test
    use all leds for testing
2018-03-19 fixed button macros
2018-03-20 added timer to devel/alex
2018-03-21 added buttons.h
2018-03-21 added leds2/ to devel/peter
2018-03-21 added missing file (buttons.h)
2018-03-21 added cover to devel/peter & bugfixed systick_delay() in led2
2018-03-22 added non-debugged Gluecksrad code
    ATTENTION: NOT DEBUGGED!!!
    new api changes of Peter has to be applied
2018-03-22 updated travis-job (echos name of current folder while building all tests)
2018-03-22 added devel/main + added modules + moved alex/gluecksrad to main/freuhlingsmarkt + bugfixes within main.c
2018-03-22 formatted gluecksrad main
2018-03-24 many fixes
    switched names of PRICES_MAX and PRICES_COUNT
    added missing breeak; statements
    changed price type to signed integer
    updated getRotatinTarget function. Not compleately tested!
2018-03-25 added DEFAULT and LENZ mode
    default: DEFAULT
    hold btnMode on startup to switch to LENZ mode
2018-03-26 Revert "formatting adjustments"
    This reverts commit e3defc1c7a93ed022443bbb679748349dea71776.
    [leds.c, main.c]
2018-03-26 added all sketch files
    [Gluecksrad.dwg, Gluecksrad_gesamt.iam, Grundplatte.ipt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]
2018-04-04 updated drawing & added link for demo-video
    [Gluecksrad.dwg]
2019-02-22 updated wheel documentation switched white <-> yellow
2021-09-26 moved glueckrad.ini to modules/
2021-09-26 added minor changes from Jasper/Peter + debounce of mode-button in menu state + some changes for testing (e.g. price count)
2021-09-26 fixed main.c (removed unused functions)
    [main.c]
2021-09-26 updated main.c (renamed some variables/constants) + time_cur --> time_now + time_anim_start --> time_state_start + LENZ --> COUNTDOWN + replaced some (time) constants with defines + changed EEPROM ke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
    [main.c]
2021-09-26 many changes to main.c! + removed unnecessary lines + updated color definitions (using 0 instead of LEDS_MIN) + renamed some states to improve readability + added/moved more delay values as defines +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
2021-10-08 minor fix to animation
    [main.c]
2021-10-08 Aktualisierung des Glücksrades für den Keplertag 2021 ~ Anordnung der Preise (sichtbar auf dem Glücksrad) ~ interne Preisanzahl
2021-10-10 fixed orientation of wheel of fortune
